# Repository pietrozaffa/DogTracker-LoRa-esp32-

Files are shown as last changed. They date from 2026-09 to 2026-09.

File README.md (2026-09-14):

# PiZaff DogTrack — firmware collare + palmare

Sistema di localizzazione per cani da caccia/ricerca, stile Garmin Astro, tutto
autocostruito su schede **Heltec WiFi LoRa 32 (V3 / V4)**.

- **Collare** — modulo GPS + LoRa che il cane porta al collo. Legge la
  posizione, la trasmette via radio, dorme il più possibile per durare a
  batteria.
- **Palmare** — ricevitore con display OLED, encoder e bussola. Mostra fino a
  **6 cani** contemporaneamente su schermata "freccia + distanza", tiene la
  traccia di ognuno e la può esportare in GPX da una mini pagina web.

Comunicazione **LoRa punto-punto a 869 MHz** (banda EU, rete privata), nessun
server, nessuna SIM, nessuna copertura cellulare richiesta.

---

## Contenuto del repository

| Percorso | Cosa contiene |
|---|---|
| `collare/` | Progetto PlatformIO del collare (`src/main.cpp`, ~1000 righe) |
| `palmare/` | Progetto PlatformIO del palmare (`src/main.cpp`, ~3100 righe) + tabelle partizioni |
| `palmare dogtrk.stl` / `.3mf` | Case del palmare pronto per la stampa 3D |
| `PiZaff_DogTrack_Manuale_A5 (2).pdf` | Manuale utente (formato A5) |
| `PiZaff_DogTrack_Libretto (1).pdf` | Libretto di istruzioni |
| `PiZaff_DogTracker_Schema (3).html` | Schema dei collegamenti (apribile nel browser) |
| `demo_gui.html` / `demo_oled.html` | Anteprima dell'interfaccia palmare, da aprire nel browser |

---

## Hardware

### Collare
- Heltec WiFi LoRa 32 **V3** (ESP32-S3, SX1262, 8 MB flash) **oppure V4**
  (16 MB flash, PA RF esterno ~28 dBm)
- GPS **u-blox NEO-M8N** (UART)
- Accelerometro **MPU6050** (I²C) — rileva se il cane si muove
- **Reed switch** + magnete — accensione/spegnimento senza pulsanti né fori
- Buzzer (feedback sonoro su accensione / reset)
- Batteria LiPo 1S

### Palmare
- Heltec WiFi LoRa 32 **V3** oppure **V4** (la V4 ha 2 MB di PSRAM: buffer
  traccia da 300 → 5000 punti per cane)
- GPS **u-blox NEO-M8N** (UART)
- Bussola **QMC5883L** (I²C) — anche quella integrata nei moduli "M8N + compass"
- Display **OLED 128×64** SSD1309/SSD1306 (SPI), es. Waveshare 2.42"
- **Encoder rotativo KY-040** con pulsante — unico controllo
- Batteria LiPo 1S

I pinout completi (con le differenze V3/V4) sono commentati in testa ai
rispettivi `src/main.cpp`. Lo schema visuale è in
`PiZaff_DogTracker_Schema (3).html`.

> **Nota V4:** su V3 e V4 alcuni GPIO cambiano funzione (sulla V4 sono
> riservati all'amplificatore RF, al connettore GNSS e al reset OLED
> integrati). Il firmware se ne occupa da solo tramite il flag `BOARD_V4`;
> basta scegliere l'ambiente di build giusto.

---

## Compilazione e flash

### Con PlatformIO (consigliato)

Installa l'estensione **PlatformIO** in VS Code, poi apri **la cartella
`collare/` o `palmare/`** (non la root del repo — sono due progetti separati).

Collare:

```bash
cd collare
pio run -e collare_v4 -t upload   # Heltec V4 (16 MB, PA esterno)
pio run -e collare_v3 -t upload   # Heltec V3 (8 MB)
```

Palmare:

```bash
cd palmare
pio run -e palmare_v4 -t upload   # Heltec V4 — usa partitions_pizaff_16mb.csv, PSRAM QSPI
pio run -e palmare_v3 -t upload   # Heltec V3 — usa partitions_pizaff.csv
```

Monitor seriale: `pio device monitor` (115200 baud). In VS Code l'ambiente si
sceglie dalla barra di stato in basso.

Le librerie (RadioLib, TinyGPSPlus, MPU6050 / Adafruit SSD1306+GFX,
QMC5883LCompass) vengono scaricate in automatico da `platformio.ini`.

### Con Arduino IDE

Il file `.csv` delle partizioni **non viene letto**. Per il palmare imposta a
mano:

- **Tools → Partition Scheme →** `Huge APP (3MB No OTA/1MB SPIFFS)`
- solo V4: **Tools → PSRAM →** `QSPI PSRAM`
- **Tools → Filesystem →** LittleFS

Il collare sta nella partizione di default, nessuna impostazione particolare.

---

## Primo utilizzo

### Collare (nessun pulsante, si usa il magnete)

| Gesto | Effetto |
|---|---|
| Magnete appoggiato **2 s** da spento | **Accensione** (5 beep) |
| Magnete appoggiato **3 s** da acceso | **Spegnimento** (deep sleep, sveglia solo a magnete) |
| Magnete tenuto **10 s** all'accensione | **Reset di fabbrica** dei parametri radio (SF/potenza) |

Il tempo minimo evita accensioni/spegnimenti accidentali (collare vicino a
oggetti metallici). All'accensione il collare cerca il fix GPS e comincia a
trasmettere; il LED/buzzer danno conferma.

### Palmare (solo l'encoder: ruota per muoverti, click per confermare)

1. **Accendi** premendo il pulsante dell'encoder.
2. Vai su **Menu → Associa**: il palmare elenca gli ID dei collari che sente in
   giro. Seleziona quello del tuo cane e dagli un nome (max 8 caratteri).
   Ripeti per ogni cane (fino a 6).
3. Torna alla **Home**: per ogni cane vedi freccia (direzione relativa alla tua
   bussola), distanza, stato fix, batteria del collare.
4. **Menu → Bussola**: calibrazione bussola (ruota il palmare su sé stesso).
5. **Menu → Mappa**: attiva il WiFi per la mappa live nel browser (vedi sotto).
6. **Menu → Tracce**: elenco delle tracce registrate, cancellazione, export GPX.
7. **Menu → Unità**: metri / piedi.
8. **Menu → Avanzate**: cambio Spreading Factor e potenza TX (vedi "Come
   funziona").

Spegnimento: voce di menu dedicata / click lungo dalla Home (deep sleep,
sveglia col pulsante encoder).

---

## Come funziona

### Il collegamento radio

- **869.525 MHz**, banda 125 kHz, CR 4/5, sync word privata `0xA7`.
- **SF (Spreading Factor) 8** di default — compromesso tra portata e frequenza
  di aggiornamento. Modificabile da palmare (SF 7–12): SF alto = più portata ma
  refresh più lento e più aria occupata.
- Pacchetto **binario compatto** (`CollarPacket`, ~30 byte) con CRC gestito da
  RadioLib: magic, ID collare, lat/lon (1e-7°), quota, velocità, rotta,
  satelliti, HDOP, batteria %, mV, contatore di sequenza + flag
  (fix / in movimento / batteria scarica / fermo / in carica).
- Il palmare risponde con `CmdPacket` (`ACK`, `STANDBY`, `WAKE`,
  `SET_SF`, `SET_PWR`).

### TX adattivo (autonomia del collare)

L'MPU6050 dice se il cane si muove:

| Stato | Intervallo TX |
|---|---|
| In movimento (o entro 15 s dall'ultimo movimento) | **2.5 s** |
| Fermo | **30 s** |

Cane fermo = poche trasmissioni = batteria che dura. Fra un invio e l'altro,
quando può, il collare va in sleep.

### Standby e sveglia da remoto

Dal palmare (**Cani → Standby**) si mette un collare in standby: la radio resta
in ascolto a bassissimo consumo e il collare si risveglia solo quando il
palmare gli manda `WAKE` (**Cani → Sveglia**). Utile per il cane a riposo tra
una battuta e l'altra senza doverlo maneggiare.

### Auto-recupero SF

Se il palmare perde il contatto, prova a ri-sincronizzarsi mandando `SET_SF` in
broadcast sui vari SF finché il collare non risponde. Il reset di fabbrica col
magnete (10 s) è la via di recupero manuale sul collare, che non ha schermo.

### Potenza TX e limiti EU

Sulla **V4** l'amplificatore esterno porta l'uscita a ~28 dBm. L'ERP dipende
dall'antenna:

| Config | ERP stimato | Limite EU (27 dBm ERP) |
|---|---|---|
| V4 + antenna 10 dBi | ~35.9 dBm | usa **12–13 dBm** di TX |
| V4 + antenna FPC 2.5 dBi | ~28.4 dBm | usa **19–20 dBm** di TX |

`LORA_PWR_DBM` nel `main.cpp` del collare (e la voce **Avanzate → Potenza** sul
palmare) regolano questo valore. **Rispetta la normativa del tuo paese.**

> A piena potenza il PA della V4 assorbe parecchia corrente durante l'impulso
> TX: se vedi riavvii casuali in trasmissione è un calo di tensione (batteria
> scarica o cavi/connettori troppo sottili) — scendi di qualche dBm.

### Mappa e tracce (WiFi del palmare)

Con **Menu → Mappa** il palmare accende un access point:

- SSID **`Pi_zaff_sys_DogTrack`**, password **`pizaff123`**
- apri **http://192.168.4.1** nel browser

La pagina mostra la posizione live dei cani e la scia. Le tracce complete sono
salvate su **LittleFS** e scaricabili in **GPX** da `/tracks`. Il buffer in RAM
serve solo a disegnare la scia sulla mappa live (300 punti/cane su V3, 5000 su
V4 grazie alla PSRAM); lo storico su file non ha questo limite.

---

## Struttura dei sorgenti

Entrambi i `main.cpp` hanno in testa un commento lungo che spiega pinout,
differenze V3/V4, e le scelte non ovvie (gestione PA RF esterno, `gpio_hold_en`
prima del deep sleep, perché serve la tabella partizioni custom sul palmare,
ecc.). È la prima cosa da leggere prima di mettere mano al codice.

---

## Licenza

Copyright (C) 2026 Pietro Zaffarano.

Questo progetto è distribuito con licenza **GNU GPL v3.0**: puoi usarlo,
studiarlo, modificarlo e ridistribuirlo, ma ogni derivato che distribuisci
deve restare open source con la stessa licenza — non può essere chiuso in un
prodotto proprietario né essere fatto passare per opera di qualcun altro.
Testo completo in [LICENSE](LICENSE).

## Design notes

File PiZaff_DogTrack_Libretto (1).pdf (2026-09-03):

# Note — manutenzione

Interventi fatti, parti sostituite, date di ricarica.

# Pi_Zaff System DogTrack

### Sistema di localizzazione GPS per cani da caccia Collare + Palmare · radio LoRa 868 MHz

MANUALE D'USO · firmware v2.14

Sistema autocostruito su hardware Heltec WiFi LoRa 32 (V3/V4).
Fino a 6 collari associabili · mappa da smartphone · tracce esportabili in GPX.

# Indice

### 1 Com'è fatto il sistema

### 2 Cosa c'è nella confezione

### 3 Accendere e spegnere

### 4 La schermata principale

### 5 Il menu

### 6 Associare un collare

### 7 Gestire i cani

### 8 Segnali acustici

### 9 La mappa sul telefono

### 10 Le tracce salvate

### 11 Impostazioni

### 12 Ricarica e manutenzione

### 13 Se qualcosa non va

### 14 Dati tecnici

### 15 Note su potenza e normativa

### 16 Pinout della scheda V4

### 17 Schema del collare

### 18 Schema del palmare

### Prima di iniziare

Questo manuale descrive un sistema autocostruito. Non è un prodotto commerciale certificato: alcune funzioni vanno tarate sul campo, e le prestazioni dipendono dal terreno, dal montaggio e dalle antenne usate.

Leggi il capitolo 15 prima del primo uso in esterna. Riguarda i limiti di potenza radio: la configurazione predefinita è impostata al massimo che l'hardware può erogare, che in Europa supera i limiti consentiti con antenne ad alto guadagno.

Il sistema è composto da due apparati che comunicano solo tra loro, senza internet, senza SIM e senza abbonamenti: il collare sul cane e il palmare in mano.

# Note — tarature

Valori modificati e perche': potenza, SF, soglie.

# Note — prove di portata

Distanze raggiunte, zone difficili, valori di SF provati.

# 1. Com'è fatto il sistema

### Due apparati, un collegamento diretto

Il collare legge la posizione dal proprio GPS e la trasmette via radio. Il palmare la riceve, la confronta con la propria posizione e ti mostra distanza e direzione verso il cane.

La radio è di tipo LoRa in collegamento diretto punto-punto: non serve rete telefonica, non serve copertura, non ci sono costi. Funziona anche dove il telefono non prende.

### Cosa vedi e cosa senti

Sul palmare | Cosa indica
Freccia nella bussola | La direzione in cui camminare per raggiungere il cane
Numero grande | Distanza in linea d'aria
Barrette in alto a sinistra | Qualità del collegamento radio col collare
Riquadri C e P | Stato GPS del Collare e del Palmare
Due batterie | Carica del collare (C) e del palmare (P)

Fino a 6 cani. Ogni collare ha un codice univoco: una volta associato, viene riconosciuto da solo a ogni accensione. Sul palmare ruoti la manopola per passare da un cane all'altro.

### Portata realistica

Ambiente | Distanza indicativa
Campo aperto, in vista | 3–5 km
Collina, vegetazione rada | 1.5–3 km
Bosco fitto | 800 m – 1.5 km

Sono valori indicativi: la portata reale dipende molto dal dislivello, dall'umidità e da come è orientata l'antenna del collare mentre il cane si muove.

Quando il segnale manca, il palmare non si svuota: continua a mostrare l'ultima posizione ricevuta, con l'indicazione di quanto tempo è passato. È lì che devi andare a cercare.

# 2. Cosa c'è nella confezione

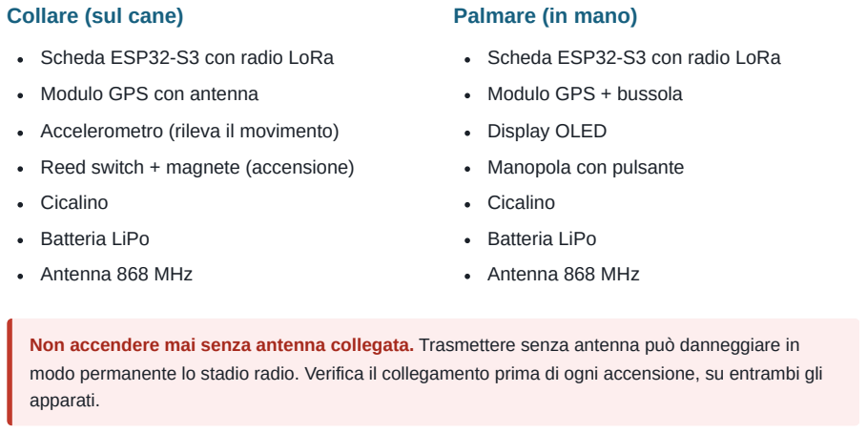
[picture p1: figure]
Collare (sul cane); Scheda ESP32-S3 con radio LoRa; Modulo GPS con antenna; Accelerometro (rileva il movimento); Reed switch + magnete (accensione); Cicalino; Batteria LiPo; Antenna 868 MHz; Palmare (in mano); Modulo GPS + bussola; Display OLED; Manopola con pulsante; apparati.

Non accendere mai senza antenna collegata. Trasmettere senza antenna può danneggiare in modo permanente lo stadio radio. Verifica il collegamento prima di ogni accensione, su entrambi gli

### Il magnete

Il collare non ha pulsanti: è sigillato. Si accende e si spegne appoggiando il magnete sul punto segnato del case. Tienilo insieme al palmare o al portachiavi.

Se il magnete si perde, il collare non si può più accendere né spegnere. Vale la pena averne uno di scorta.

Collare: 2 beep ogni 30 s | Non sente più il palmare

### Rete WiFi

Nome rete | Pi_zaff_sys_DogTrack
Password | pizaff123
Indirizzo | 192.168.4.1

# Riepilogo comandi

Pagina da consultare al volo, senza cercare nel manuale.

### Palmare

Gesto | Effetto
Tieni premuto 2 s | Accende
Tieni premuto 5 s | Spegne (con barra di conferma)
Ruota in schermata principale | Cambia cane
Click in schermata principale | Apre il menu
Ruota nelle liste | Scorre le voci
Ruota nelle schermate informative | Esce
Click dove c'è un'azione extra | Esegue l'azione (spegni WiFi, cancella tracce)

### Collare (magnete)

Durata | Effetto
2 secondi (da spento) | Accende — 1 beep
3 secondi (da acceso o in standby) | Spegne — 3 beep
10 secondi | Ripristino radio — 5 beep rapidi

### Suoni

Suono | Significato
Palmare: 3 toni in discesa | Segnale perso
Palmare: 2 toni in salita | Segnale ritrovato
Palmare: 2 toni lunghi | Cane in ferma
Palmare: 3 beep uguali | Batteria collare quasi scarica
Collare: 3 toni in discesa | Messo in standby dal palmare
Collare: 2 toni in salita | Svegliato dal palmare

# 3. Accendere e spegnere

### Palmare

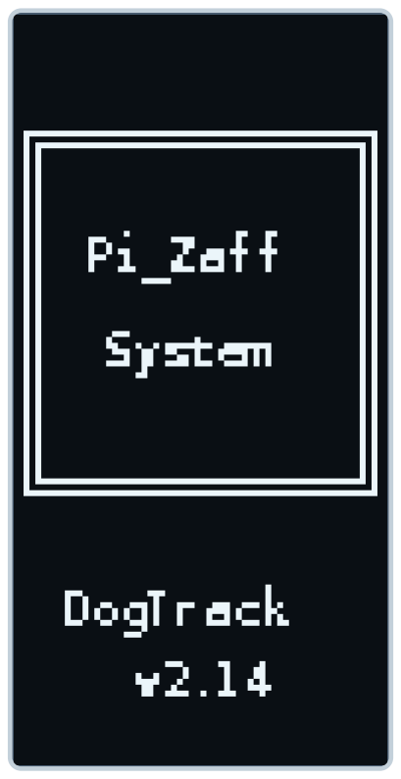
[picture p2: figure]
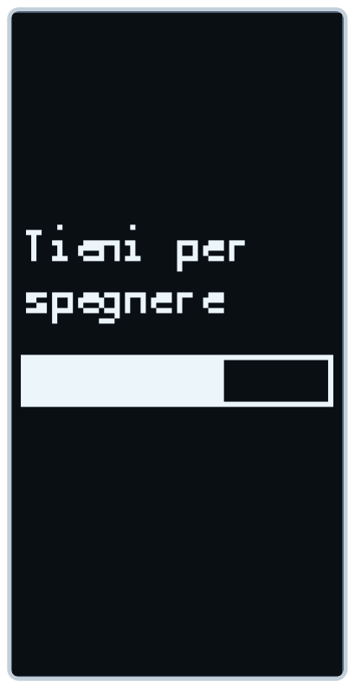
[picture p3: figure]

Schermata di avvio Spegnimento in corso

Accensione
Tieni premuto il pulsante della manopola per 2 secondi. Compare il logo, poi la schermata principale.

Spegnimento
Tieni premuto per 5 secondi. Dopo 1.5 secondi appare una barra che si riempie: quando è piena il palmare si spegne.

I 2 secondi richiesti all'accensione servono a evitare che si accenda da solo urtandolo nello zaino.

### Collare

Operazione | Come si fa | Conferma
Accensione | Magnete appoggiato sul punto segnato per 2 secondi | 1 beep
Spegnimento | Magnete tenuto per 3 secondi, poi toglilo

3 beep

Spegnimento a distanza

Dal palmare puoi mettere un collare in standby senza averlo in mano (Menu → Cani → il cane → Standby). Il collare risponde con tre toni discendenti e si spegne. Per riaccenderlo: stessa strada, voce Sveglia; risponde con due toni ascendenti.

Attenzione alla differenza. Un collare spento col magnete non si può riaccendere da remoto: la radio è completamente spenta. Solo lo standby dal palmare può essere annullato a distanza. Se prevedi di riaccenderlo senza averlo in mano, usa lo standby, non il magnete.

Collare in standby. Il magnete tenuto 3 secondi su un collare in standby lo spegne del tutto (tre beep), non lo risveglia. È lo stesso gesto dello spegnimento normale: non devi ricordarti in che stato fosse.

# 4. La schermata principale

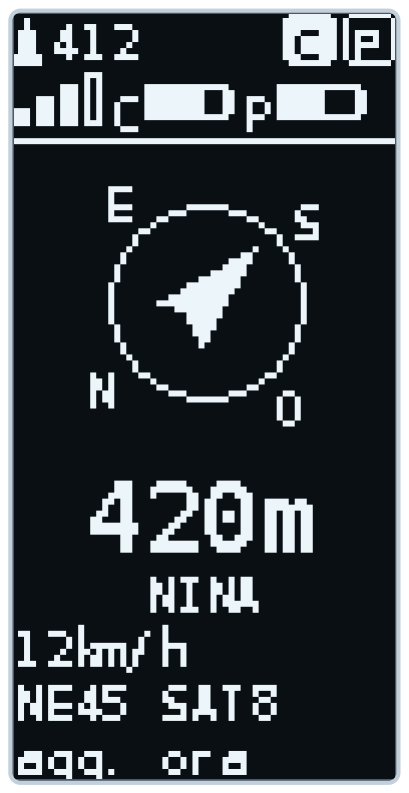
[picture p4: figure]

Situazione normale

Dall'alto verso il basso

Quota (con il triangolino): altitudine dell'ultima posizione del cane. Ogni 5 secondi lascia il posto per 3 secondi all'orologio (con la sua iconcina): l'ora italiana viene calcolata dai satelliti, cambio ora legale compreso, senza bisogno di regolarla.
Riquadri C e P (in alto a destra): stato del GPS di Collare e Palmare. Pieno = posizione valida; vuoto = sta cercando i satelliti; lampeggiante = nessun dato. Se un telefono è collegato al WiFi, al posto della P compare l'icona del telefono.

Cambiando cane con la manopola, per 3 secondi compare il contatore (es. 2/3 ) al posto di quota e orologio.

Barrette + due batterie: qualità del collegamento, carica del collare (C) e del palmare (P).
Bussola: la freccia punta verso il cane; le lettere N/E/S/O ruotano con te. Numero grande: distanza. Subito sotto, centrato, il nome del cane: fino a 6 lettere, ben leggibile.

Ultime tre righe: cosa sta facendo il cane, direzione e satelliti, quando è arrivato l'ultimo aggiornamento.

La freccia è relativa a te. Se punta in alto, il cane è davanti a te così come stai tenendo il palmare. Ruotando il palmare la freccia si aggiorna: giragli attorno finché non punta in alto, poi cammina dritto.

### Le tre situazioni che devi riconoscere

Il magnete e la bussola. Se tieni il magnete del collare nello stesso case del palmare, calibra la bussola con il magnete già al suo posto: il campo fisso viene compensato. Spostandolo dopo, la freccia sbaglia finché non lo rimetti dov'era.

Pi_Zaff System · DogTrack · manuale d'uso firmware v2.14
Sistema autocostruito — nessuna garanzia implicita di funzionamento o conformità

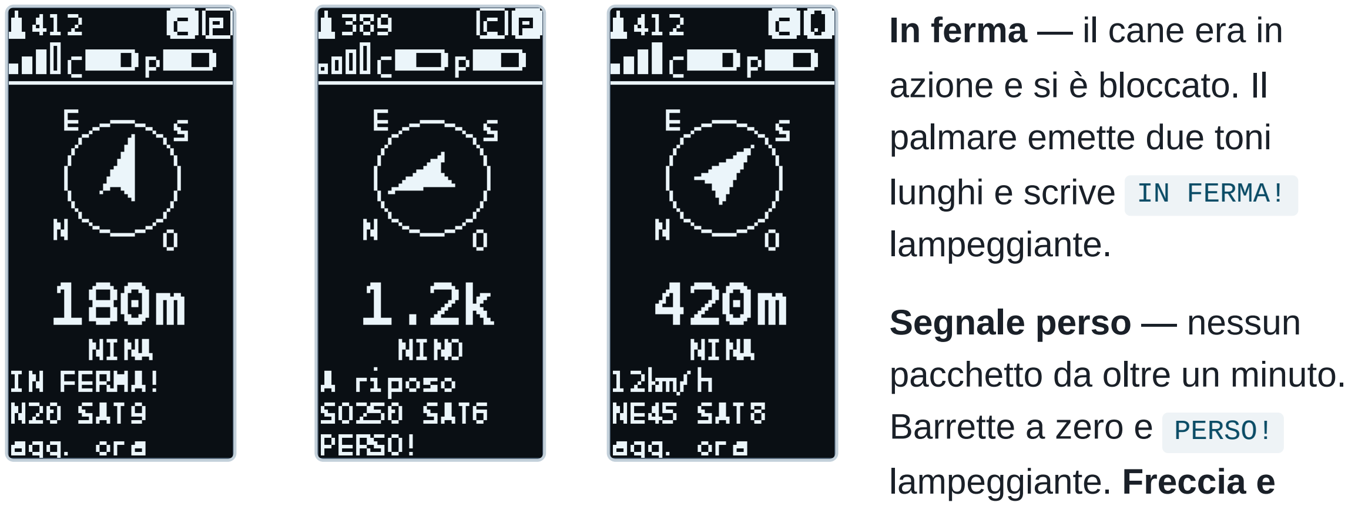
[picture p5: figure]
In ferma — il cane era in azione e si è bloccato. Il palmare emette due toni lunghi e scrive IN FERMA! lampeggiante.; Segnale perso — nessun pacchetto da oltre un minuto. Barrette a zero e PERSO! lampeggiante. Freccia e

# 18. Schema del palmare

Modulo | Suo pin | Pin scheda | Note
GPS + bussola | TX | GPIO 33 | Incrociato
RX | GPIO 16 | Su V3: GPIO 34
SDA | GPIO 41 | Bussola
SCL | GPIO 42 | Bussola
VCC | 3V3
GND | GND
Display | CLK | GPIO 38
DIN | GPIO 39
CS | GPIO 40

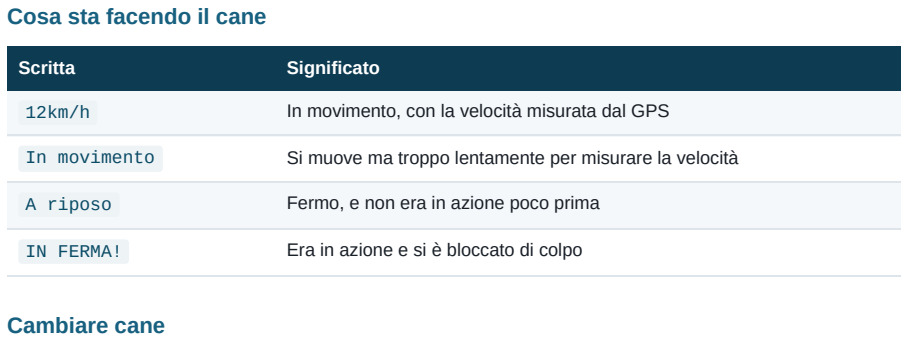
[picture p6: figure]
Cosa sta facendo il cane; Scritta; Significato; Cambiare cane

DC GPIO 15 Su V3: GPIO 21 | A riposo | Fermo, e non era in azione poco prima
RST | GPIO 47
| VCC | 3V3
| GND | GND
Manopola | CLK (A) | GPIO 2 | Vedi avvertenza sotto
| DT (B) | GPIO 6
| SW | GPIO 4 | Su V3: GPIO 7
| + | 3V3
| GND | GND
Cicalino | + | GPIO 21 | Vedi avvertenza
| − | GND
Batteria | JST | connettore scheda
Antenna | u.FL | connettore scheda

### Posizionamento nel case

Display in verticale, con il connettore verso il basso

Bussola lontana dal magnete: almeno 6–7 cm, angolo opposto del case Bussola lontana dalla batteria e da parti metalliche
Manopola raggiungibile con una mano sola: la userai con i guanti

In ferma
lampeggia + doppio tono

Segnale perso
ultima posizione nota

Telefono connesso
icona al posto della P

distanza restano sull'ultima posizione buona.

Telefono connesso —
l'icona del telefono
sostituisce la P quando
qualcuno sta guardando la
mappa dal cellulare.
12km/h | In movimento, con la velocità misurata dal GPS
In movimento | Si muove ma troppo lentamente per misurare la velocità
IN FERMA! | Era in azione e si è bloccato di colpo

In questa schermata ruota la manopola per passare da un cane all'altro. Per tre secondi compare in alto il contatore (es. 2/3 ) così sai a quale sei arrivato.

# 5. Il menu

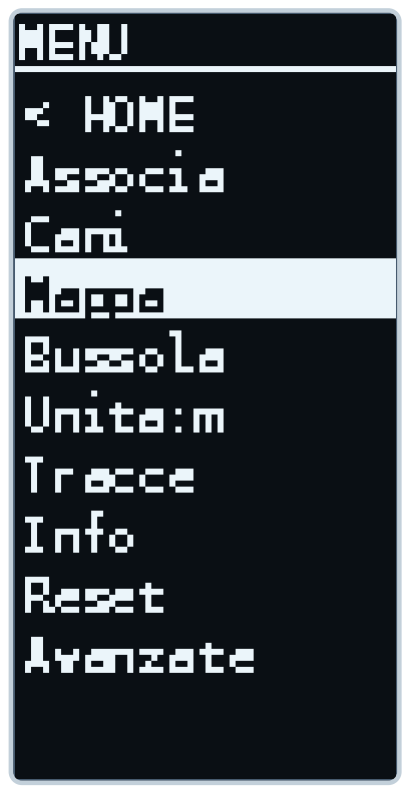
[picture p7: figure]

Le dieci voci del menu

Come ci si muove

RUOTA | Sposta la selezione
CLICK | Conferma / entra
CLICK LUNGO | Solo nell'editor dei nomi: conferma il nome

Una regola sola per uscire: in tutte le schermate informative si esce ruotando la manopola. Nelle liste (Menu, Cani, Avanzate) c'è invece una riga < HOME o < indietro in cima. Dove esiste un'azione in più (Mappa WiFi, Tracce) il click la esegue.

Voce | A cosa serve
< HOME | Torna alla schermata principale
Associa | Registra un collare nuovo (capitolo 6)
Cani | Rinomina, spegni, sveglia o elimina un cane (capitolo 7)
Mappa | Accende il WiFi per vedere la mappa dal telefono (capitolo 9)
Bussola | Avvia la calibrazione della bussola (capitolo 11)
Unita: | Alterna metri/chilometri e piedi/miglia
Tracce | Quante sessioni salvate e quanto spazio occupano (capitolo 10)
Info | Dati tecnici del collegamento e ultima posizione
Reset | Cancella tutto e riporta il palmare come nuovo
Avanzate | Portata del segnale e potenza di trasmissione (capitolo 11)

# 17. Schema del collare

Tutti i collegamenti da fare. Radio, gestione batteria e presa USB sono già cablati sulla scheda: si collegano solo i moduli esterni.

Modulo | Suo pin | Pin scheda | Note
GPS | TX | GPIO 33 | Incrociato: TX del GPS sull'RX della scheda
RX | GPIO 16 | Su V3: GPIO 34
VCC | 3V3 | Mai a 5V
GND | GND
Accelerometro | SDA | GPIO 41
SCL | GPIO 42
VCC | 3V3
GND | GND
Reed switch | capo 1 | GPIO 4 | Su V3: GPIO 7
capo 2 | GND | Non ha polarità
Cicalino | + | GPIO 21 | Tipo passivo. Vedi avvertenza
− | GND
Batteria | JST | connettore scheda | Verificare la polarità
Antenna | u.FL | connettore scheda | Collegare prima di alimentare

### Posizionamento nel case

Antenna GPS rivolta verso l'alto: è la faccia che deve vedere il cielo

Antenna GPS lontana dalla batteria: il pacco può schermare il segnale
Reed switch piatto contro la parete, con la parete assottigliata in quel punto e un segno inciso all'esterno per ritrovarlo
Fili corti e fissati: il collare prende urti e vibrazioni continue
Batteria su biadesivo, mai incollata direttamente

Massa comune. Tutti i GND dei moduli devono arrivare al GND della scheda. Senza massa condivisa i segnali non funzionano o danno letture instabili.

2 5V
alimentazione
— | Da USB
1 | GND massa
—

### Radio, display integrato e altri

| Pin | Stato | Funzione nel progetto
— | GPIO 8 LoRa NSS | RISERV. | Radio — già cablato a bordo
— | GPIO 9
LoRa SCK
RISERV. | Radio
— | GPIO 10
LoRa MOSI
RISERV. | Radio
— | GPIO 11
LoRa MISO
RISERV. | Radio
— | GPIO 12
LoRa RST
RISERV. | Radio
— | GPIO 13
LoRa BUSY
RISERV. | Radio
— | GPIO 14
LoRa DIO1
RISERV. | Radio
— | GPIO 17
OLED SDA
RISERV. | Display integrato
— | GPIO 18
OLED SCL
RISERV. | Display integrato
— | GPIO 15
—
USATO | Display DC (nostro)
— | GPIO 16
—
USATO | GPS RX ← scheda (nostro)

I pin 38–42 sulla V4 sono collegati anche al connettore GNSS dedicato. Restano utilizzabili come pin normali finché quel connettore non viene usato: nel nostro montaggio il GPS è collegato a filo, quindi sono liberi per display e bussola.

Strapping pin. GPIO 3 e 45 vengono letti dal chip all'accensione per decidere come avviarsi. Se un modulo esterno li tiene a livello alto o basso, la scheda può non partire. Vanno lasciati liberi.

Schermata Info

Cosa dice la schermata Info

SF8 | Modalità radio (più alto = più portata, meno velocità)
RSSI | Potenza del segnale ricevuto in dBm (meno negativo = meglio)
SNR | Rapporto segnale/rumore
Cal | Bussola calibrata sì/no
BP / BC | Batteria Palmare / Collare
Pos | Ultima posizione valida del cane
HDOP | Qualità geometrica del fix: sotto 2 ottimo, sopra 10 scarso

# 6. Associare un collare

Va fatto una sola volta per collare. Da lì in poi viene riconosciuto da solo a ogni accensione, anche dopo che la batteria si è scaricata del tutto.

Collari rilevati | Scrittura del nome

Procedura

1. Accendi il collare col magnete e tienilo vicino
2. Sul palmare: Menu → Associa
3. Entro pochi secondi compare il codice del collare
4. Ruota fino a selezionarlo e fai click
5. Scrivi il nome (vedi sotto) e conferma con un click lungo

Se non compare nulla: verifica che il collare sia acceso (1 beep) e che l'antenna sia collegata su entrambi.

Come si scrive il nome

RUOTA | Scorre le lettere disponibili (A–Z, 0–9, spazio)
CLICK | Conferma la lettera e passa alla successiva
CLICK LUNGO | Termina e salva il nome

Il nome può avere fino a 9 caratteri, ma nella schermata principale ne vengono mostrati i primi 6: conviene sceglierlo corto e riconoscibile.

Più cacciatori nella stessa zona? Ogni collare ha un codice unico, quindi non rischi di vedere il cane di un altro. Se però volete isolamento totale tra gruppi, si può cambiare un parametro radio nel firmware — va fatto su tutti gli apparati dello stesso gruppo.

## 16. Pinout V4 (continua)

### Connettore J2 (lato destro)

Pin | Pin | Stato | Funzione nel progetto
18 | GPIO 19 USB_D− · U1RST | RISERV. | USB nativo
17 | GPIO 20
USB_D+ · U1CTS
RISERV. | USB nativo
16 | GPIO 26
SPICS1
RISERV. | Bus flash interno
15 | GPIO 21
OLED_RST
USATO | Cicalino — vedi avvertenza
14 | GPIO 48
—
libero | Non usato
13 | GPIO 47
—
USATO | Display RST
12 | GPIO 33
SPIIO4 · FSPIHD
USATO | GPS TX → scheda
11 | GPIO 34
VGNSS_Ctrl ·
FSPICS0
RISERV. | Alimentazione GNSS
10 | GPIO 35 LED_Write · FSPID | RISERV. | LED integrato
9 | GPIO 36
Vext_Ctrl · FSPICLK
USATO | Alimentazione periferiche
8 | GPIO 0
USER_SW
RISERV. | Pulsante PRG
7 | RST
RST_SW
RISERV. | Pulsante reset
6 | GPIO 43
U0TXD
RISERV. | Console seriale
5 | GPIO 44
U0RXD
RISERV. | Console seriale
4 | Ve
uscita commutata
— | Controllata da GPIO 36
3 | Ve uscita commutata
—

13 GPIO 2
FEM_EN · TOUCH2
USATO | Manopola A — vedi avvertenza
12 | GPIO 1
VBAT_Read ·
ADC1_CH0
USATO | Lettura batteria
11 | GPIO 38
GNSS_RX · FSPIWP
USATO | Display CLK
10 | GPIO 39
GNSS_TX · MTCK
USATO | Display DIN
9 | GPIO 40
GNSS_Wake ·
MTDO
USATO | Display CS
8 | GPIO 41
GNSS_PPS · MTDI
USATO | Bussola SDA
7 | GPIO 42
GNSS_RST · MTMS
USATO | Bussola SCL
6 | GPIO 45
—
STRAP. | Strapping (VDD_SPI)
5 | GPIO 46
FEM_PA
RISERV. | Amplificatore RF
4 | GPIO 37
ADC_Ctrl · FSPIQ
USATO | Abilita partitore batteria
3 | 3V3
alimentazione
— | Moduli esterni
2 | 3V3
alimentazione

—

1 GND
massa
— | Massa comune

# 7. Gestire i cani

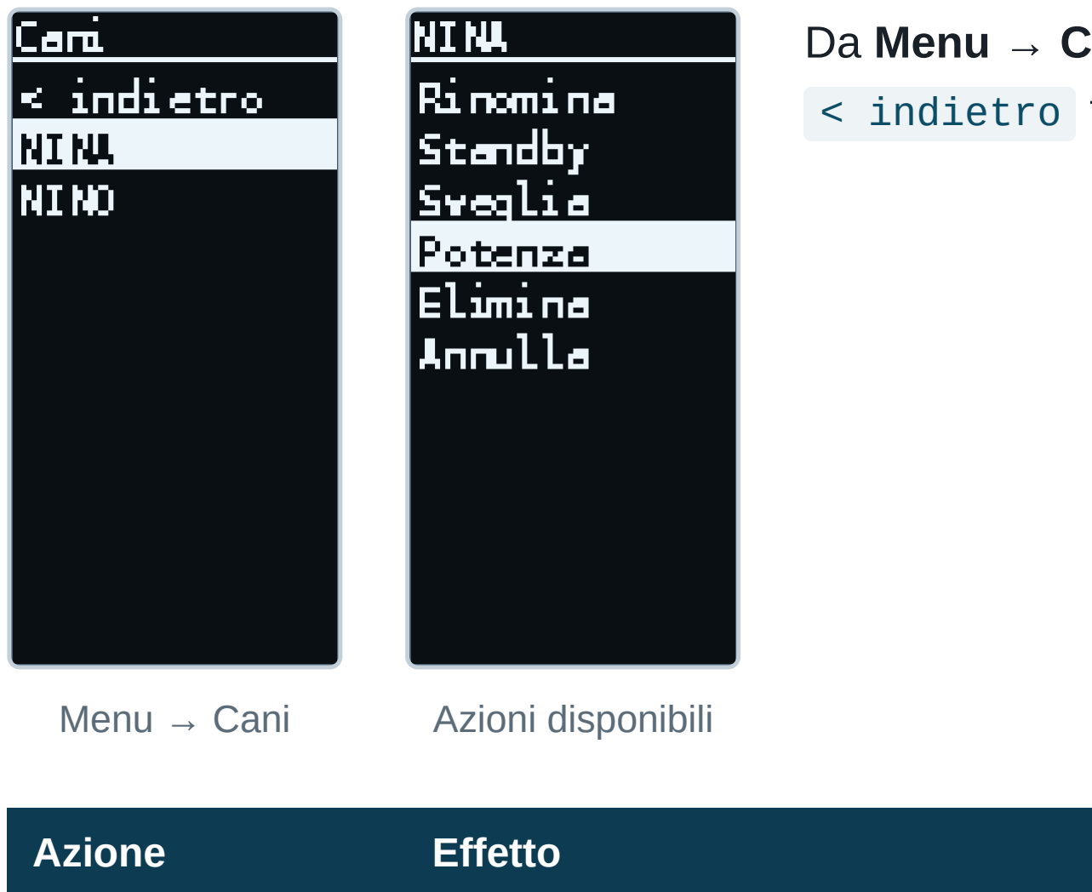
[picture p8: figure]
Menu → Cani; Azioni disponibili; Azione; Effetto

Da Menu → Cani scegli il cane e poi l'azione. La prima riga < indietro torna al menu senza fare nulla.

Rinomina | Cambia il nome, senza perdere l'associazione
Standby | Spegne il collare a distanza. Parte al prossimo pacchetto ricevuto: può servire qualche secondo. Conferma: tre toni discendenti dal collare
Sveglia | Riaccende un collare in standby. Il palmare trasmette per 4 secondi; il collare risponde con due toni ascendenti
Potenza | Cambia la potenza di trasmissione di quel collare (comando via radio). Se il comando si perde, resta il valore precedente
Elimina | Rimuove l'associazione. Chiede conferma
Annulla | Torna indietro

La Sveglia funziona solo dopo uno Standby. Se il collare è stato spento col magnete la sua radio è spenta e non può sentire nulla: va riacceso col magnete.

Eliminare e riassociare

Un collare eliminato non è perso: riaccendendolo ricompare tra quelli rilevabili in Associa e puoi registrarlo di nuovo, anche con un nome diverso.

# 8. Segnali acustici

I suoni sono pochi e volutamente diversi tra loro: servono a farti capire cosa succede senza guardare lo schermo, che in battuta è la cosa che conta.

### Palmare

Suono | Significato
Tre toni discendenti | Segnale col cane perso
Due toni ascendenti | Segnale ritrovato
Due toni lunghi | Il cane è andato in ferma
Tre beep uguali | Batteria del collare quasi scarica

### Collare

Suono | Significato
1 beep | Acceso col magnete
3 beep uguali | Spento col magnete
Tre toni discendenti | Messo in standby dal palmare
Due toni ascendenti | Svegliato dal palmare
2 beep ogni 30 secondi | Non sente più il palmare da oltre un minuto
5 beep rapidi | Magnete tenuto 10 secondi: ripristino radio di emergenza (capitolo 13)

Come distinguerli a orecchio: i toni "in scala" (che salgono o scendono) sono sempre comandi arrivati via radio; i beep tutti uguali sono operazioni fatte col magnete o avvisi di batteria.

Durante la battuta il collare è silenzioso: non suona per non disturbare il cane né la selvaggina. Le uniche eccezioni sono l'accensione, lo spegnimento e l'avviso di collegamento perso.

# 16. Pinout della scheda V4

Riferimento completo dei connettori della scheda Heltec WiFi LoRa 32 V4, con indicazione di cosa è usato dal progetto e cosa non va toccato. Serve se devi rifare un collegamento o aggiungere qualcosa.

USATO usato dal progetto | RISERV. riservato dalla scheda | STRAP. strapping | libero libero

Pin con funzione dedicata sulla V4. Secondo il pin layout ufficiale questi pin sono già impegnati sulla scheda: GPIO 7 e GPIO 2 controllano l'amplificatore radio, GPIO 34 alimenta il connettore GNSS, GPIO 21 resetta il display integrato.

Due eccezioni nel montaggio attuale. Su questo esemplare il GPIO 5 non ha mai risposto (verificato scambiando i fili), quindi la manopola è stata spostata sul GPIO 2; il cicalino è sul GPIO 21 perché i pin provati prima non erano raggiungibili sulla scheda. Entrambi funzionano, ma sono pin che il layout indica come occupati.

Verifica consigliata: con i due apparati distanti qualche decina di metri, guarda l'RSSI in Menu → Info mentre giri la manopola avanti e indietro. Se il valore oscilla o crolla, il GPIO 2 è davvero collegato all'amplificatore e conviene spostare la manopola.

### Connettore J3 (lato sinistro)

Pin | Pin | Stato | Funzione nel progetto
18 | GPIO 7
VFEM_Ctrl ·
TOUCH7 ·
ADC1_CH6
RISERV. | Controllo amplificatore RF
17 | GPIO 6
TOUCH6 ·
ADC1_CH5
USATO | Manopola B
16 | GPIO 5
TOUCH5 ·
ADC1_CH4
libero | Non usato (vedi nota)
15 | GPIO 4
TOUCH4 ·
ADC1_CH3
USATO | Pulsante manopola / reed
14 | GPIO 3
TOUCH3 ·
ADC1_CH2
STRAP. | Strapping (JTAG)

### Perché esistono questi limiti

La banda 868 MHz è condivisa con altri sistemi, alcuni dei quali importanti: antifurti, apparecchiature mediche, sensori industriali. I limiti servono a far convivere tutti. In Italia il superamento dei limiti di emissione è sanzionato dal Codice delle comunicazioni elettroniche.

La responsabilità dell'uso è di chi lo mette in funzione. Questo è un apparato autocostruito, privo di certificazione: sta a te configurarlo in modo conforme alle norme del posto in cui lo usi.

# 9. La mappa sul telefono

Il palmare può creare una rete WiFi propria: collegandoti con il telefono vedi i cani su una mappa vera. Funziona con qualsiasi telefono, Android o iPhone, senza installare niente.

Menu → Mappa

Come collegarsi

1. Sul palmare: Menu → Mappa
2. Sul telefono, tra le reti WiFi scegli Pi_zaff_sys_DogTrack
3. Password: pizaff123
4. Apri il browser: la pagina si apre da sola. Altrimenti digita 192.168.4.1

Ruota per uscire lasciando il WiFi acceso, click per uscire spegnendolo.

### Cosa si vede nella pagina

La tua posizione come freccia che ruota con te
Ogni cane con il suo nome, e la scia del percorso fatto
Schede in basso: distanza, andatura, segnale, satelliti e batteria di ogni cane. Toccando una scheda quel cane diventa quello attivo anche sul palmare
Tasto “i” su ogni scheda: dettagli completi (coordinate, quota, qualità del fix)
Tipo di mappa: stradale, satellite o topografica

Trail: mostra il percorso storico del cane selezionato

Le mappe hanno bisogno di internet. Le immagini della mappa vengono scaricate dal telefono tramite la rete dati mentre resta collegato al palmare. Dove non c'è campo, la pagina passa da sola a una vista radar: cerchi con le distanze e i cani posizionati attorno a te. Funziona completamente

Consuma batteria. Il WiFi acceso incide parecchio sull'autonomia del palmare. Usalo quando ti serve il quadro d'insieme, poi spegnilo (Menu → Mappa → click). Se un telefono è collegato, in alto nella schermata principale l'icona del telefono te lo ricorda.

# 10. Le tracce salvate

Il palmare registra da solo il percorso di tutti i cani, senza che tu debba attivare nulla. Ogni accensione crea una sessione separata.

Menu → Tracce

La schermata mostra quante sessioni sono salvate e quanto spazio occupano.

RUOTA | Esci
CLICK | Vai alla richiesta di cancellazione totale

La cancellazione totale elimina tutte le sessioni e non è recuperabile. Viene chiesta conferma: ruota per annullare.

### Scaricarle sul telefono

1. Collegati alla mappa (capitolo 9)
2. In fondo alla pagina apri Tracce salvate
3. Per ogni sessione: data, cani coinvolti e numero di punti
4. GPX scarica il file, X elimina quella sessione

Il file GPX è un formato standard: si apre in Google Earth, OsmAnd, Garmin BaseCamp e in qualunque programma di cartografia. Contiene una traccia separata per ogni cane, con l'orario di ogni punto — puoi rivedere la battuta come una registrazione.

Lo spazio non si esaurisce mai. Quando la memoria si riempie, la sessione più vecchia viene cancellata automaticamente per fare posto a quella in corso. La battuta di oggi non si perde mai.

Scarica le tracce che ti interessano a fine giornata: una volta sul telefono o sul computer sono al sicuro anche se la pulizia automatica libera spazio in futuro.

# 15. Note su potenza e normativa

Leggi questo capitolo prima del primo uso in esterna. Riguarda un aspetto legale, non solo tecnico.

### Com'è configurato il sistema

Il firmware è impostato al massimo che l'hardware può erogare: 22 dBm dal chip radio, che sulle schede V4 diventano circa 28 dBm in uscita grazie all'amplificatore integrato.

### Il limite europeo

In Europa, sulla banda usata da questo sistema, il limite di potenza irradiata (ERP) è di 27 dBm. La potenza irradiata non dipende solo dalla radio, ma anche dall'antenna:

ERP = potenza in uscita + guadagno antenna − 2.15

Configurazione | ERP risultante | Rispetto al limite
Scheda V4 + antenna 10 dBi | circa 35.9 dBm | ampiamente sopra
Scheda V4 + antenna 2.5 dBi | circa 28.4 dBm | sopra
Scheda V3 + antenna 10 dBi | circa 29.9 dBm | sopra

### Come rientrare nei limiti

Si abbassa un solo valore nel firmware ( LORA_PWR_DBM ) e si ricompila:

Configurazione | Valore da impostare
Scheda V4 con antenna 10 dBi | 12 – 13
Scheda V4 con antenna 2.5 dBi | 19 – 20
Scheda V3 con antenna 10 dBi | 19

Quanto si perde davvero? Meno di quanto sembri. La portata cresce molto lentamente con la potenza: in bosco, dove l'ambiente assorbe gran parte del segnale, la differenza tra il massimo e il valore a norma è dell'ordine del 20–30% di distanza, non del doppio. Per guadagnare portata reale conviene agire sulla modalità radio e sul posizionamento dell'antenna, che rendono di più.

2 – 5 | Buono, adatto all'uso normale
5 – 10 | Discreto: posizione un po' incerta
oltre 10 | Scarso: da non prendere alla lettera

L'HDOP misura come sono disposti i satelliti in cielo, non quanti sono: pochi satelliti ben distribuiti danno una posizione migliore di tanti satelliti ammassati nella stessa zona.

# 11. Impostazioni

### Calibrazione della bussola

Calibrazione in corso

Serve perché il palmare sappia com'è orientato. Senza calibrazione la freccia non è affidabile. Va fatta almeno una volta, e ripetuta se noti che punta in modo strano.

1. Menu → Bussola
2. Muovi il palmare disegnando un otto in aria, ampio, per circa 15 secondi
3. La calibrazione viene salvata: resta anche dopo lo spegnimento

Il magnete disturba la bussola. Fai la calibrazione con il magnete nel suo alloggio abituale, lontano da metalli, auto e strutture in ferro. Se lo togli o lo avvicini, la freccia può sbagliare finché non lo rimetti a posto.

### Unità di misura

Menu → Unita: alterna tra metrico (metri e chilometri) e imperiale (piedi e miglia). La voce mostra l'impostazione attuale.

### Impostazioni dal telefono

Nella pagina della mappa, il pulsante ingranaggio in alto a destra apre le stesse impostazioni con la tastiera del telefono: unità di misura, declinazione magnetica e avvio della calibrazione della bussola.

Declinazione magnetica

È la differenza tra il nord della bussola e il nord delle mappe: cambia da zona a zona. È preimpostata per il sud Italia (+3.5°). Se usi il sistema molto lontano da lì, cerca il valore della tua zona e impostalo.

### Avanzate: portata e potenza

Menu → Avanzate

Qui si regolano i due parametri radio che prima si potevano cambiare solo ricompilando il programma. La riga ? Che sono? apre una spiegazione a schermo.

SF | Quanto lontano arriva il segnale. Valori alti = più portata ma aggiornamenti più lenti
Potenza | Forza di trasmissione del palmare. Non influisce sui collari

Cambiare la potenza

La potenza è indipendente per ogni apparato, quindi cambiarla non ha controindicazioni: quella del palmare si regola da Avanzate, quella di un singolo collare da Cani → il cane → Potenza. Se il comando al collare si perde, resta semplicemente il valore di prima.

Cambiare l'SF: leggere prima di farlo

L'SF deve essere uguale su palmare e collari. Se fossero diversi non si sentirebbero più, e un collare sigillato non si può correggere a mano. Per questo il cambio segue una procedura protetta.

Trasmissione in corso | Riuscito | Annullato

Scelto il nuovo valore, il palmare trasmette il cambio per 40 secondi usando ancora il vecchio SF, così tutti i collari lo ricevono — anche quelli fermi, che trasmettono solo ogni 30 secondi.

Se tutti rispondono, il cambio è confermato. Se anche uno solo non risponde, il palmare torna da solo al valore precedente: meglio rinunciare al cambio che restare senza collegamento.

Non spegnere il palmare durante quei 40 secondi e tieni i collari accesi e a portata. Se qualcosa va storto e un collare resta su un SF diverso, si recupera col magnete: vedi il capitolo 13.

### Reset totale

# 14. Dati tecnici

Voce | Valore
Frequenza radio | 869.525 MHz (banda ISM europea 868)
Tipo di collegamento | LoRa punto-punto diretto, nessuna rete o gateway
Modalità radio | SF regolabile 7–12 (predefinito 8), banda 125 kHz, correzione 4/5
Potenza | Regolabile fino a 22 dBm dal chip, per apparato (vedi capitolo 15)
Aggiornamento posizione | 2.5 s in movimento · 30 s da fermo
Precisione GPS | 2–3 m in campo aperto; 5–10 m sotto vegetazione fitta
Collari associabili | 6
Lunghezza nome | 9 caratteri (6 visibili nella schermata principale)
Memoria tracce | Circolare: la sessione più vecchia lascia posto alla nuova
Esportazione | GPX standard, una traccia per cane
Rete WiFi del palmare | Pi_zaff_sys_DogTrack · password pizaff123 · 192.168.4.1
Watchdog | Attivo: riavvia da solo in caso di blocco del programma
Ricarica | USB-C su entrambi gli apparati

### Cosa significano i numeri del segnale

RSSI | Barrette | Qualità
oltre −95 dBm | 4 | Ottima
−95 / −105 | 3 | Buona
−105 / −113 | 2 | Sufficiente
−113 / −120 | 1 | Al limite
sotto −120 dBm | 0 | Collegamento perso

### HDOP: quanto fidarsi della posizione

Valore | Significato
sotto 2 | Ottimo: satelliti ben distribuiti

### Ripristino radio col magnete

Se un collare resta su parametri radio diversi dal palmare, non lo senti più e non puoi correggerlo da remoto. C'è una via d'uscita che non richiede di aprire il case:

1. Appoggia il magnete sul punto segnato e tienilo per 10 secondi
2. Il collare emette 5 beep rapidi: i parametri radio sono tornati a quelli di fabbrica
3. Riporta anche il palmare allo stesso valore standard (Menu → Avanzate → SF), e torneranno a sentirsi

Il ripristino tocca solo i parametri radio: l'associazione col palmare, il nome del cane e le altre impostazioni restano al loro posto.

Se un apparato resta bloccato su una schermata e non risponde a nulla, l'unico rimedio è scollegare e ricollegare la batteria. Sul collare sigillato questo significa aprire il case.

Menu → Reset cancella tutto: collari associati, nomi, calibrazione e impostazioni. Il palmare riparte come nuovo e i collari vanno riassociati. Le tracce salvate si cancellano invece da Menu → Tracce.

# 12. Ricarica e manutenzione

### Ricarica

Entrambi gli apparati si ricaricano via USB-C, con lo stesso cavo. La ricarica è gestita dalla scheda: si può lasciare collegato senza problemi.

Su un collare sigillato, il connettore USB è il punto più delicato per la tenuta all'acqua. Se il tuo case ha un tappo, richiudilo bene dopo ogni ricarica.

### Autonomia

Situazione | Consumo
Cane in movimento | Massimo: trasmette ogni 2.5 secondi
Cane fermo | Ridotto: trasmette ogni 30 secondi
Batteria sotto il 15% | Gli intervalli raddoppiano automaticamente
Palmare con WiFi acceso | Sensibilmente più alto

L'autonomia va misurata sul campo. Dipende da quanto si muove il cane, dalla temperatura e dalla batteria montata. Prima di fidarti, fai una prova a giornata intera con l'uso reale.

### Pulizia e cura

Sciacqua il collare con acqua dolce dopo fango o pioggia; non usare getti in pressione Controlla ogni tanto che l'antenna sia ben avvitata e il cavo integro
Se non lo usi per settimane, spegni entrambi col magnete e con la pressione lunga
Le batterie al litio si conservano meglio a metà carica: evita di lasciarle scariche per mesi

### Prima di ogni uscita

1. Antenne collegate su entrambi
2. Batterie cariche (visibili nella schermata principale)
3. Collare acceso: 1 beep di conferma
4. Sul palmare, riquadri C e P pieni: entrambi i GPS hanno agganciato
5. Magnete in tasca

# 13. Se qualcosa non va

Sintomo | Causa probabile e rimedio
Il palmare non si accende | Il pulsante va tenuto 2 secondi pieni. Se non basta, la batteria è scarica: collega l'USB e riprova.
Il collare non fa il beep | Magnete non nel punto giusto, o non tenuto 2 secondi. Se il case è spesso il magnete potrebbe essere troppo debole: prova a premerlo bene sul punto segnato.
Il riquadro P lampeggia | Il GPS del palmare non risponde: problema di collegamento interno. Se invece è vuoto ma fisso, sta solo cercando i satelliti — vai all'aperto e attendi.
Il GPS non aggancia mai | Serve cielo libero. Al primo avvio dopo giorni di inattività può richiedere qualche minuto. Sotto tettoie, in auto o in casa spesso non aggancia affatto.
Nessun segnale dal collare | Verifica che sia acceso (1 beep) e associato. Controlla le antenne. Avvicinati: se a pochi metri funziona, è un problema di portata o di ostacoli.

Va peggio da vicino che
lontano

A distanza molto ravvicinata e a piena potenza il ricevitore può saturare. È normale: allontanati di qualche metro.

La freccia punta a caso | Bussola da calibrare (capitolo 11). Verifica anche di non avere il magnete o oggetti metallici vicino al palmare.
Si riavvia mentre trasmette | Non è un difetto del programma ma un calo di tensione: batteria scarica o di scarsa qualità, connettore ossidato, fili di alimentazione sottili.
La pagina mappa non si apre | Controlla di essere collegato alla rete del palmare e non a un'altra. Digita 192.168.4.1 a mano. Il telefono a volte avvisa "rete senza internet": accetta di restare collegato.
Mappa grigia, si vede solo il radar | Manca la copertura dati sul telefono. È il comportamento previsto: il radar funziona comunque e mostra distanze e direzioni.
La Sveglia non funziona | Funziona solo se il collare era in standby. Se era stato spento col magnete, va riacceso col magnete.
Il collare suona due beep ogni 30s | Non sente più il palmare. Verifica che il palmare sia acceso e con antenna collegata.
Un collare non si sente più dopo un cambio SF | È rimasto su un valore diverso. Vedi qui sotto il ripristino radio col magnete.
Compare ERR LoRa | La radio non ha risposto all'avvio: controlla l'antenna e i collegamenti. Il palmare resta comunque spegnibile tenendo premuto 5 secondi, e continua a riprovare da solo.

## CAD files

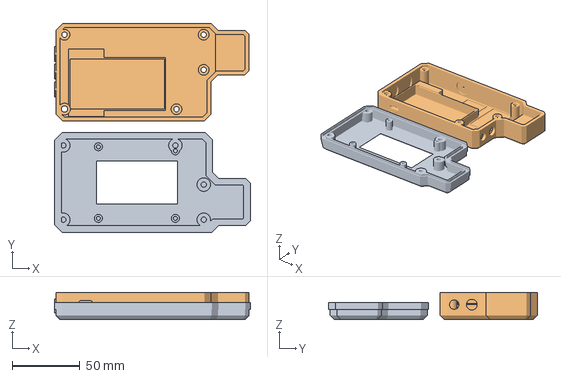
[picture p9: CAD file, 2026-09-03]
palmare dogtrk.3mf
145.1 x 154.5 x 20.0 mm
palmare dogtrk.stl_2
palmare dogtrk.stl_1

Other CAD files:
palmare dogtrk.stl

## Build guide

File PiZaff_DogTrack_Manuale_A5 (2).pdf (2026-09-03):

# Pi_Zaff System DogTrack

### Sistema di localizzazione GPS per cani da caccia Collare + Palmare · radio LoRa 868 MHz

MANUALE D'USO · firmware v2.14

Sistema autocostruito su hardware Heltec WiFi LoRa 32 (V3/V4).
Fino a 6 collari associabili · mappa da smartphone · tracce esportabili in GPX.

# Indice

### 1 Com'è fatto il sistema

### 2 Cosa c'è nella confezione

### 3 Accendere e spegnere

### 4 La schermata principale

### 5 Il menu

### 6 Associare un collare

### 7 Gestire i cani

### 8 Segnali acustici

### 9 La mappa sul telefono

### 10 Le tracce salvate

### 11 Impostazioni

### 12 Ricarica e manutenzione

### 13 Se qualcosa non va

### 14 Dati tecnici

### 15 Note su potenza e normativa

### 16 Pinout della scheda V4

### 17 Schema del collare

### 18 Schema del palmare

### Prima di iniziare

Questo manuale descrive un sistema autocostruito. Non è un prodotto commerciale certificato: alcune funzioni vanno tarate sul campo, e le prestazioni dipendono dal terreno, dal montaggio e dalle

Leggi il capitolo 15 prima del primo uso in esterna. Riguarda i limiti di potenza radio: la configurazione predefinita è impostata al massimo che l'hardware può erogare, che in Europa supera i limiti consentiti con antenne ad alto guadagno.

Il sistema è composto da due apparati che comunicano solo tra loro, senza internet, senza SIM e senza abbonamenti: il collare sul cane e il palmare in mano.

# 1. Com'è fatto il sistema

### Due apparati, un collegamento diretto

Il collare legge la posizione dal proprio GPS e la trasmette via radio. Il palmare la riceve, la confronta con la propria posizione e ti mostra distanza e direzione verso il cane.

La radio è di tipo LoRa in collegamento diretto punto-punto: non serve rete telefonica, non serve copertura, non ci sono costi. Funziona anche dove il telefono non prende.

### Cosa vedi e cosa senti

Sul palmare | Cosa indica
Freccia nella bussola | La direzione in cui camminare per raggiungere il cane
Numero grande | Distanza in linea d'aria
Barrette in alto a sinistra | Qualità del collegamento radio col collare
Riquadri C e P | Stato GPS del Collare e del Palmare
Due batterie | Carica del collare (C) e del palmare (P)

Fino a 6 cani. Ogni collare ha un codice univoco: una volta associato, viene riconosciuto da solo a ogni accensione. Sul palmare ruoti la manopola per passare da un cane all'altro.

### Portata realistica

Ambiente | Distanza indicativa
Campo aperto, in vista | 3–5 km
Collina, vegetazione rada | 1.5–3 km
Bosco fitto | 800 m – 1.5 km

Sono valori indicativi: la portata reale dipende molto dal dislivello, dall'umidità e da come è orientata l'antenna del collare mentre il cane si muove.

Quando il segnale manca, il palmare non si svuota: continua a mostrare l'ultima posizione ricevuta, con l'indicazione di quanto tempo è passato. È lì che devi andare a cercare.

# 2. Cosa c'è nella confezione

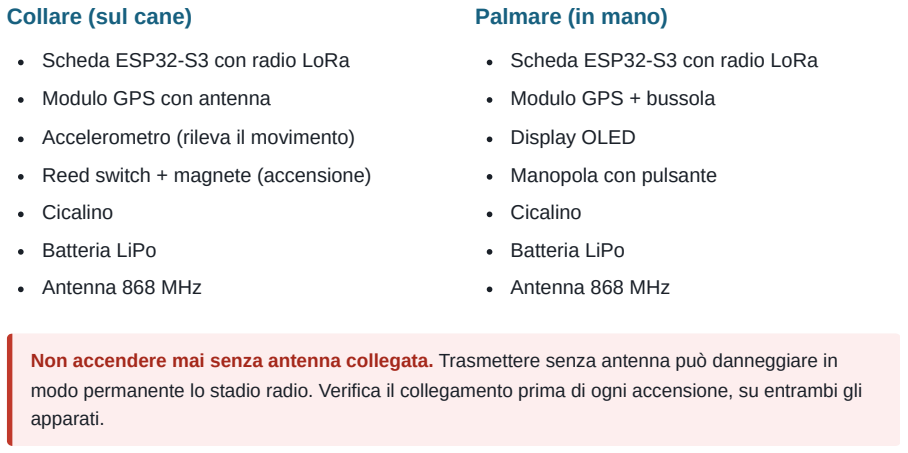
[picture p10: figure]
Collare (sul cane); Scheda ESP32-S3 con radio LoRa; Modulo GPS con antenna; Accelerometro (rileva il movimento); Reed switch + magnete (accensione); Cicalino; Batteria LiPo; Antenna 868 MHz; Palmare (in mano); Modulo GPS + bussola; Display OLED; Manopola con pulsante; apparati.

Non accendere mai senza antenna collegata. Trasmettere senza antenna può danneggiare in modo permanente lo stadio radio. Verifica il collegamento prima di ogni accensione, su entrambi gli

### Il magnete

Il collare non ha pulsanti: è sigillato. Si accende e si spegne appoggiando il magnete sul punto segnato del case. Tienilo insieme al palmare o al portachiavi.

Se il magnete si perde, il collare non si può più accendere né spegnere. Vale la pena averne uno di

# 3. Accendere e spegnere

### Palmare

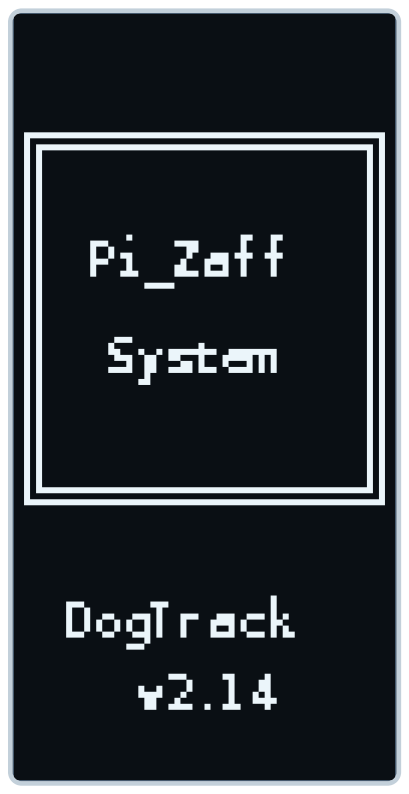
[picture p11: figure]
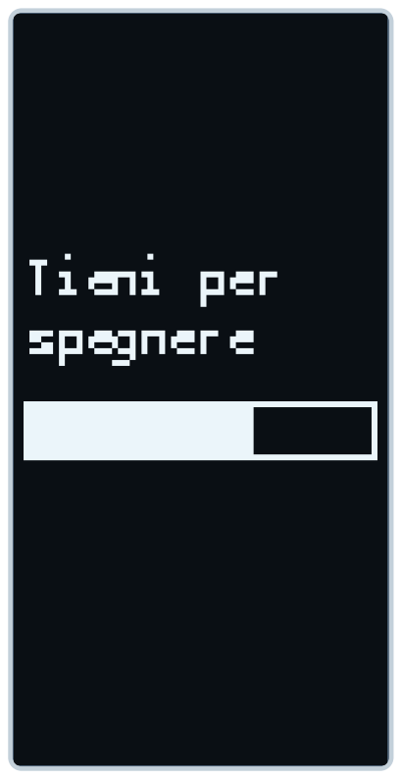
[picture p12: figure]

Schermata di avvio Spegnimento in corso

Accensione
Tieni premuto il pulsante della manopola per 2 secondi. Compare il logo, poi la schermata principale.

Spegnimento
Tieni premuto per 5 secondi. Dopo 1.5 secondi appare una barra che si riempie: quando è piena il palmare si spegne.

I 2 secondi richiesti all'accensione servono a evitare che si accenda da solo urtandolo nello zaino.

### Collare

Operazione | Come si fa | Conferma
Accensione | Magnete appoggiato sul punto segnato per 2 secondi | 1 beep
Spegnimento | Magnete tenuto per 3 secondi, poi toglilo

3 beep

Spegnimento a distanza

Dal palmare puoi mettere un collare in standby senza averlo in mano (Menu → Cani → il cane → Standby). Il collare risponde con tre toni discendenti e si spegne. Per riaccenderlo: stessa strada, voce Sveglia; risponde con due toni ascendenti.

Attenzione alla differenza. Un collare spento col magnete non si può riaccendere da remoto: la radio è completamente spenta. Solo lo standby dal palmare può essere annullato a distanza. Se prevedi di riaccenderlo senza averlo in mano, usa lo standby, non il magnete.

Collare in standby. Il magnete tenuto 3 secondi su un collare in standby lo spegne del tutto (tre beep), non lo risveglia. È lo stesso gesto dello spegnimento normale: non devi ricordarti in che stato

# 4. La schermata principale

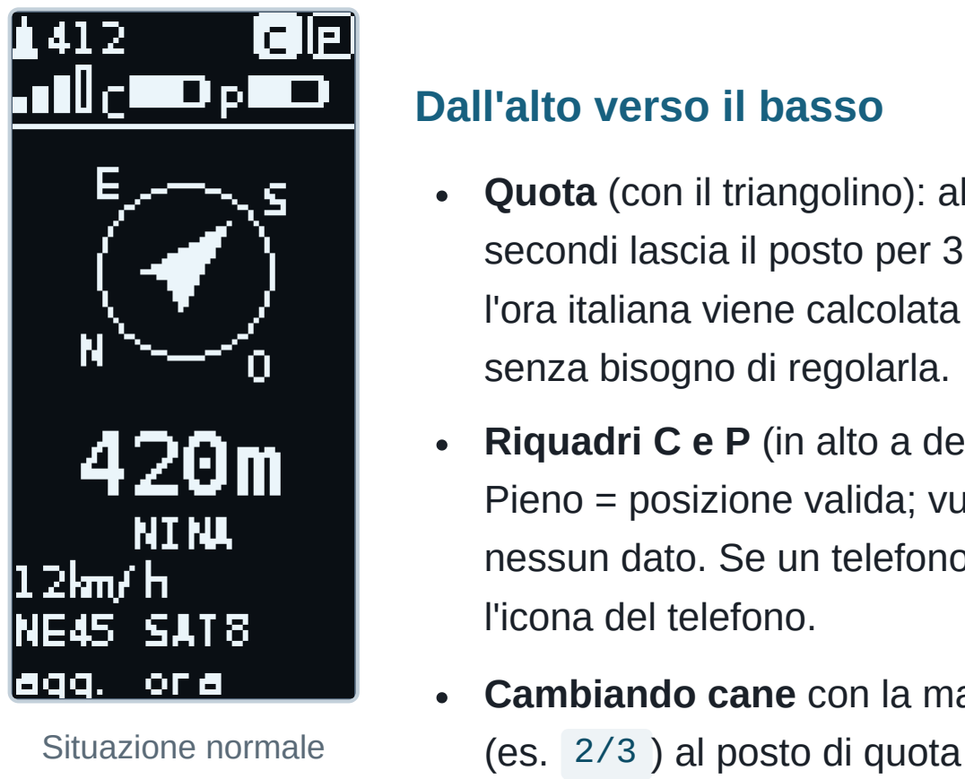
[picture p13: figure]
Situazione normale; Dall'alto verso il basso; senza bisogno di regolarla.; l'icona del telefono.

Quota (con il triangolino): altitudine dell'ultima posizione del cane. Ogni 5 secondi lascia il posto per 3 secondi all'orologio (con la sua iconcina): l'ora italiana viene calcolata dai satelliti, cambio ora legale compreso,

Riquadri C e P (in alto a destra): stato del GPS di Collare e Palmare. Pieno = posizione valida; vuoto = sta cercando i satelliti; lampeggiante = nessun dato. Se un telefono è collegato al WiFi, al posto della P compare

Cambiando cane con la manopola, per 3 secondi compare il contatore (es. 2/3 ) al posto di quota e orologio.

Barrette + due batterie: qualità del collegamento, carica del collare (C) e del palmare (P).
Bussola: la freccia punta verso il cane; le lettere N/E/S/O ruotano con te. Numero grande: distanza. Subito sotto, centrato, il nome del cane: fino a 6 lettere, ben leggibile.

Ultime tre righe: cosa sta facendo il cane, direzione e satelliti, quando è arrivato l'ultimo aggiornamento.

La freccia è relativa a te. Se punta in alto, il cane è davanti a te così come stai tenendo il palmare. Ruotando il palmare la freccia si aggiorna: giragli attorno finché non punta in alto, poi cammina dritto.

### Le tre situazioni che devi riconoscere

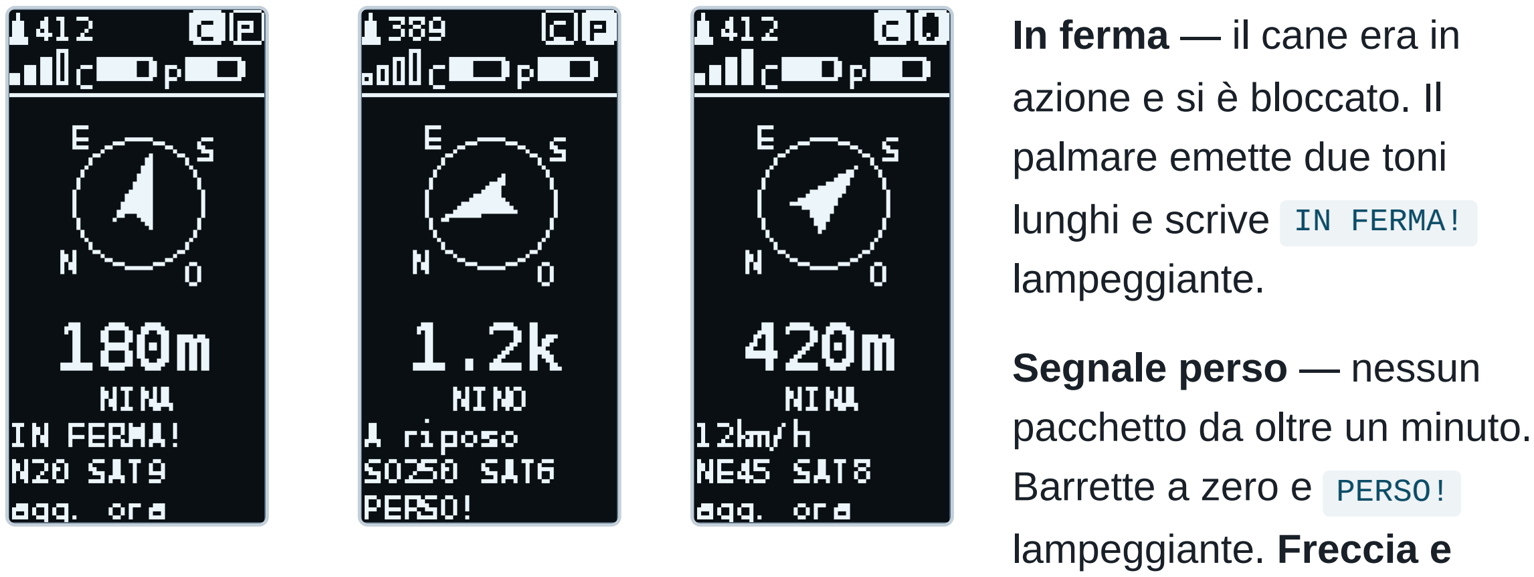
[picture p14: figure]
In ferma — il cane era in azione e si è bloccato. Il palmare emette due toni lunghi e scrive IN FERMA! lampeggiante.; Segnale perso — nessun pacchetto da oltre un minuto. Barrette a zero e PERSO! lampeggiante. Freccia e

In ferma
lampeggia + doppio tono

Segnale perso
ultima posizione nota

Telefono connesso
icona al posto della P

distanza restano sull'ultima posizione buona.

Telefono connesso —
l'icona del telefono
sostituisce la P quando
qualcuno sta guardando la
mappa dal cellulare.

Cosa sta facendo il cane

Scritta | Significato
12km/h | In movimento, con la velocità misurata dal GPS
In movimento | Si muove ma troppo lentamente per misurare la velocità
A riposo | Fermo, e non era in azione poco prima
IN FERMA! | Era in azione e si è bloccato di colpo

Cambiare cane

In questa schermata ruota la manopola per passare da un cane all'altro. Per tre secondi compare in alto il contatore (es. 2/3 ) così sai a quale sei arrivato.

# 5. Il menu

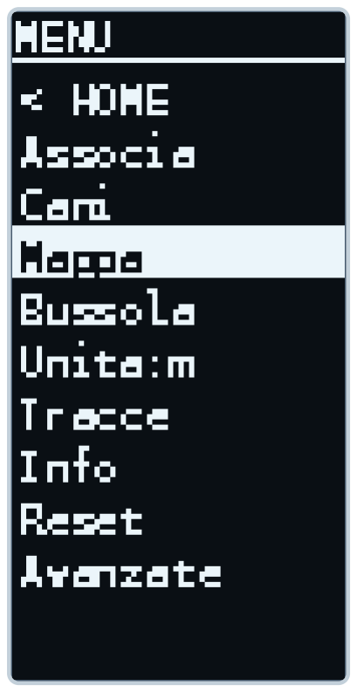
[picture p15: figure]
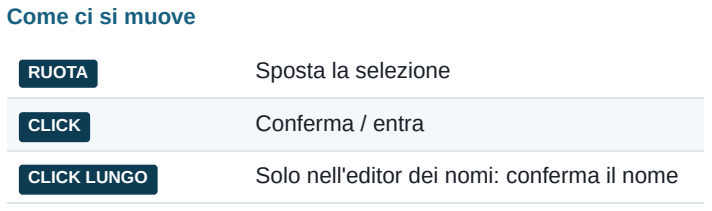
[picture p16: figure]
Come ci si muove; RUOTA; Sposta la selezione; CLICK; Conferma / entra

CLICK LUNGO | Solo nell'editor dei nomi: conferma il nome

Una regola sola per uscire: in tutte le schermate informative si esce ruotando la manopola. Nelle liste (Menu, Cani, Avanzate) c'è invece una riga < HOME o < indietro in cima. Dove esiste un'azione in più (Mappa WiFi,

Voce | A cosa serve
< HOME | Torna alla schermata principale
Associa | Registra un collare nuovo (capitolo 6)
Cani | Rinomina, spegni, sveglia o elimina un cane (capitolo 7)
Mappa | Accende il WiFi per vedere la mappa dal telefono (capitolo 9)
Bussola | Avvia la calibrazione della bussola (capitolo 11)
Unita: | Alterna metri/chilometri e piedi/miglia
Tracce | Quante sessioni salvate e quanto spazio occupano (capitolo 10)
Info | Dati tecnici del collegamento e ultima posizione
Reset | Cancella tutto e riporta il palmare come nuovo
Avanzate | Portata del segnale e potenza di trasmissione (capitolo 11)

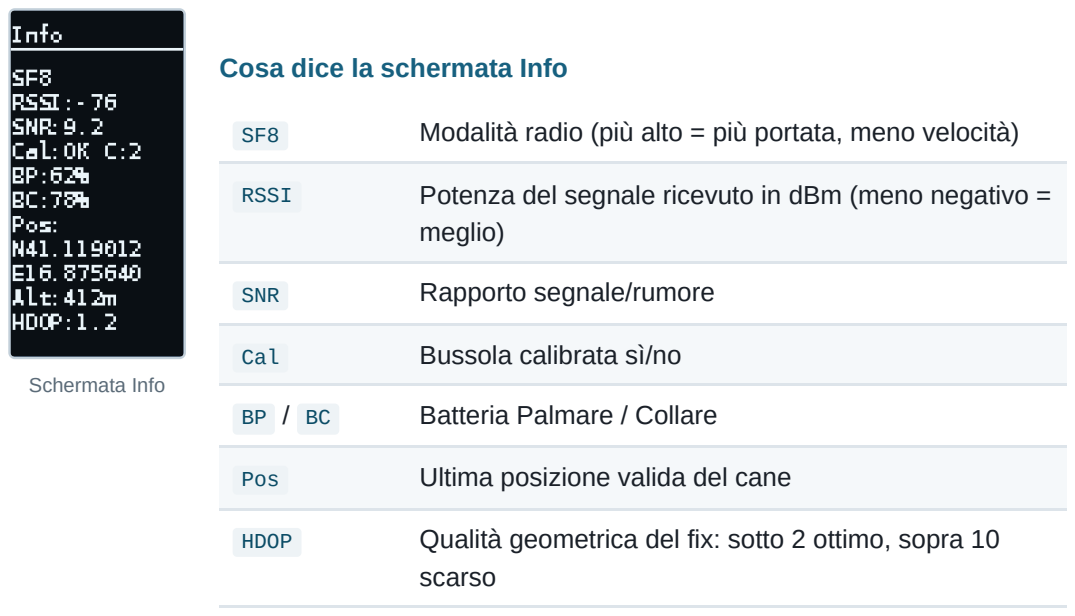
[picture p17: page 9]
Schermata Info; Modalità radio (più alto = più portata, meno velocità); RSSI; Potenza del segnale ricevuto in dBm (meno negativo =; meglio); SNR; Rapporto segnale/rumore; Cal; Bussola calibrata sì/no; Batteria Palmare / Collare; Pos; Ultima posizione valida del cane; HDOP; Qualità geometrica del fix: sotto 2 ottimo, sopra 10; scarso

Cosa dice la schermata Info

# 6. Associare un collare

Va fatto una sola volta per collare. Da lì in poi viene riconosciuto da solo a ogni accensione, anche dopo che la batteria si è scaricata del tutto.

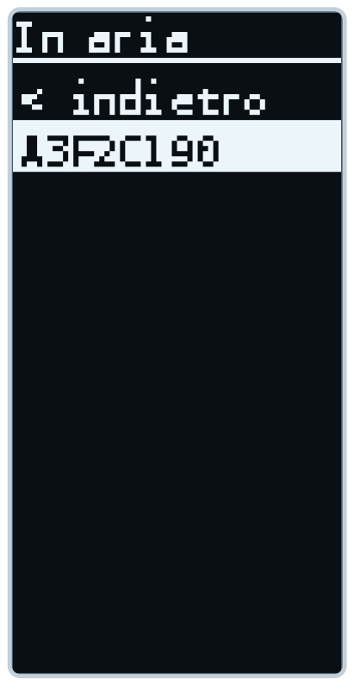
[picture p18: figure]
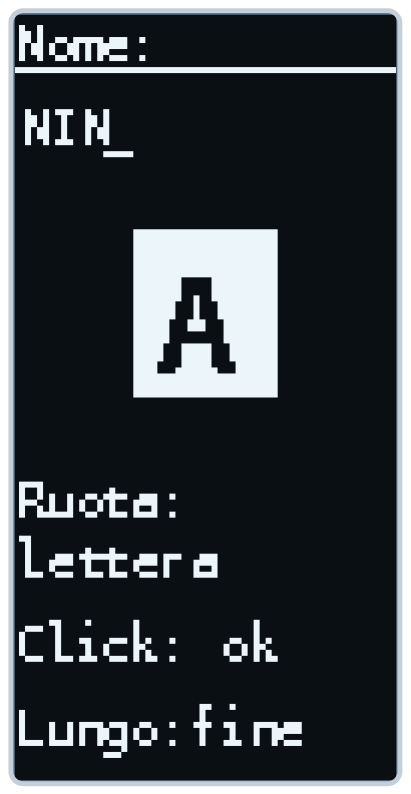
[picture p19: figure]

Collari rilevati | Scrittura del nome

Procedura

1. Accendi il collare col magnete e tienilo vicino
2. Sul palmare: Menu → Associa
3. Entro pochi secondi compare il codice del collare
4. Ruota fino a selezionarlo e fai click
5. Scrivi il nome (vedi sotto) e conferma con un click lungo

Se non compare nulla: verifica che il collare sia acceso (1 beep) e che l'antenna sia collegata su entrambi.

RUOTA | Scorre le lettere disponibili (A–Z, 0–9, spazio)
CLICK | Conferma la lettera e passa alla successiva

Il nome può avere fino a 9 caratteri, ma nella schermata principale ne vengono mostrati i primi 6:

Più cacciatori nella stessa zona? Ogni collare ha un codice unico, quindi non rischi di vedere il cane di un altro. Se però volete isolamento totale tra gruppi, si può cambiare un parametro radio nel firmware — va fatto su tutti gli apparati dello stesso gruppo.

# 7. Gestire i cani

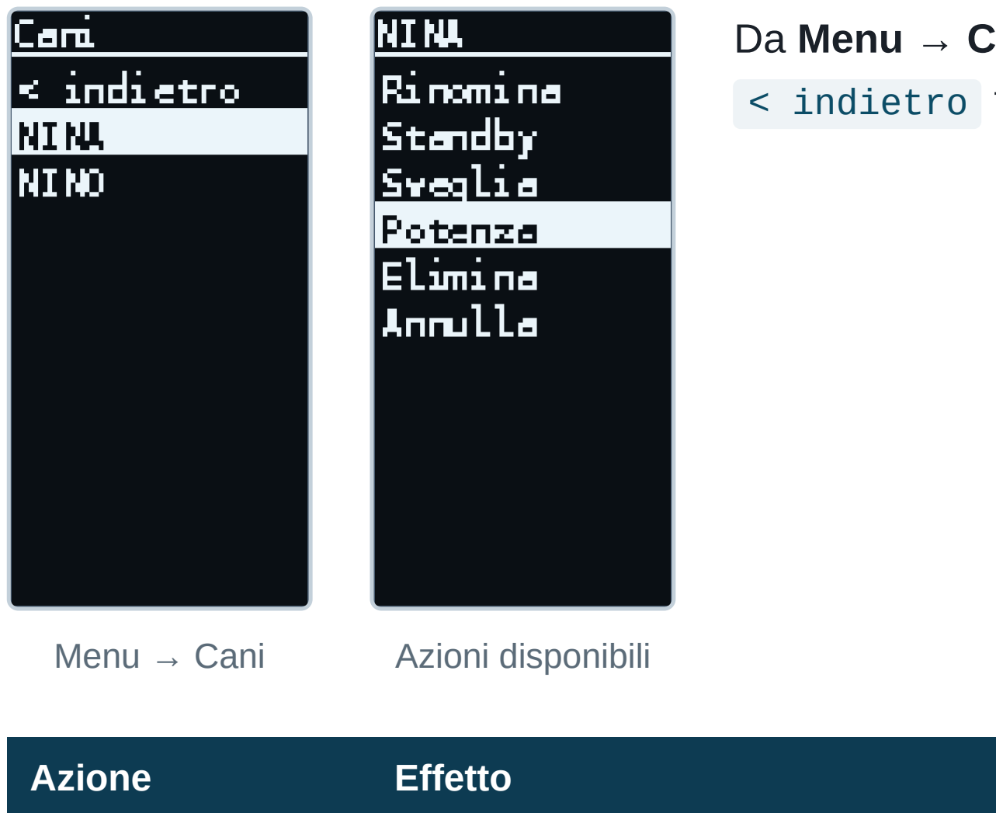
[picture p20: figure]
Menu → Cani; Azioni disponibili; Azione; Effetto

Da Menu → Cani scegli il cane e poi l'azione. La prima riga < indietro torna al menu senza fare nulla.

Rinomina | Cambia il nome, senza perdere l'associazione
Standby | Spegne il collare a distanza. Parte al prossimo pacchetto ricevuto: può servire qualche secondo. Conferma: tre toni discendenti dal collare
Sveglia | Riaccende un collare in standby. Il palmare trasmette per 4 secondi; il collare risponde con due toni ascendenti
Potenza | Cambia la potenza di trasmissione di quel collare (comando via radio). Se il comando si perde, resta il valore precedente

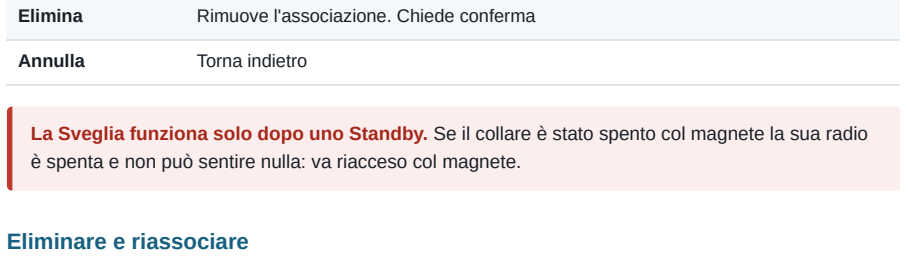
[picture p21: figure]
Elimina; Rimuove l'associazione. Chiede conferma; Annulla; Torna indietro; Eliminare e riassociare

La Sveglia funziona solo dopo uno Standby. Se il collare è stato spento col magnete la sua radio è spenta e non può sentire nulla: va riacceso col magnete.

Un collare eliminato non è perso: riaccendendolo ricompare tra quelli rilevabili in Associa e puoi registrarlo di nuovo, anche con un nome diverso.

# 8. Segnali acustici

I suoni sono pochi e volutamente diversi tra loro: servono a farti capire cosa succede senza guardare lo schermo, che in battuta è la cosa che conta.

### Palmare

Suono | Significato
Tre toni discendenti | Segnale col cane perso
Due toni ascendenti | Segnale ritrovato
Due toni lunghi | Il cane è andato in ferma
Tre beep uguali | Batteria del collare quasi scarica

### Collare

Suono | Significato
1 beep | Acceso col magnete
3 beep uguali | Spento col magnete
Tre toni discendenti | Messo in standby dal palmare
Due toni ascendenti | Svegliato dal palmare
2 beep ogni 30 secondi | Non sente più il palmare da oltre un minuto
5 beep rapidi | Magnete tenuto 10 secondi: ripristino radio di emergenza (capitolo 13)

Come distinguerli a orecchio: i toni "in scala" (che salgono o scendono) sono sempre comandi arrivati via radio; i beep tutti uguali sono operazioni fatte col magnete o avvisi di batteria.

Durante la battuta il collare è silenzioso: non suona per non disturbare il cane né la selvaggina. Le uniche eccezioni sono l'accensione, lo spegnimento e l'avviso di collegamento perso.

# 9. La mappa sul telefono

Il palmare può creare una rete WiFi propria: collegandoti con il telefono vedi i cani su una mappa vera. Funziona con qualsiasi telefono, Android o iPhone, senza installare niente.

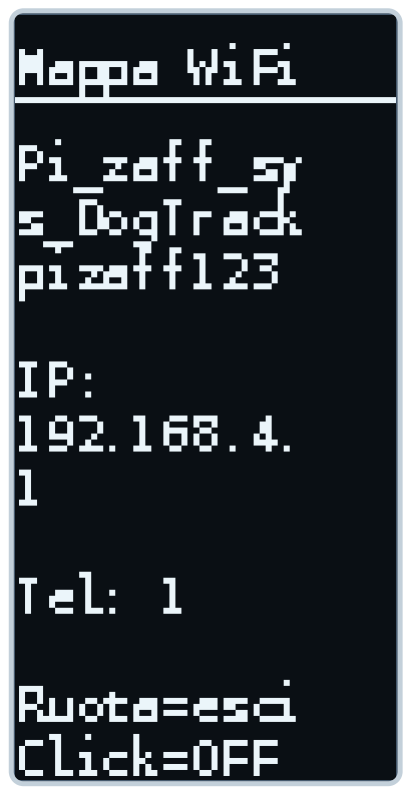
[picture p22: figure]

Menu → Mappa

Come collegarsi

1. Sul palmare: Menu → Mappa
2. Sul telefono, tra le reti WiFi scegli Pi_zaff_sys_DogTrack
3. Password: pizaff123
4. Apri il browser: la pagina si apre da sola. Altrimenti digita 192.168.4.1

Ruota per uscire lasciando il WiFi acceso, click per uscire spegnendolo.

### Cosa si vede nella pagina

La tua posizione come freccia che ruota con te
Ogni cane con il suo nome, e la scia del percorso fatto
Schede in basso: distanza, andatura, segnale, satelliti e batteria di ogni cane. Toccando una scheda quel cane diventa quello attivo anche sul palmare
Tasto “i” su ogni scheda: dettagli completi (coordinate, quota, qualità del fix)
Tipo di mappa: stradale, satellite o topografica

Trail: mostra il percorso storico del cane selezionato

Le mappe hanno bisogno di internet. Le immagini della mappa vengono scaricate dal telefono tramite la rete dati mentre resta collegato al palmare. Dove non c'è campo, la pagina passa da sola a una vista radar: cerchi con le distanze e i cani posizionati attorno a te. Funziona completamente

Consuma batteria. Il WiFi acceso incide parecchio sull'autonomia del palmare. Usalo quando ti serve il quadro d'insieme, poi spegnilo (Menu → Mappa → click). Se un telefono è collegato, in alto nella schermata principale l'icona del telefono te lo ricorda.

# 10. Le tracce salvate

Il palmare registra da solo il percorso di tutti i cani, senza che tu debba attivare nulla. Ogni accensione crea una sessione separata.

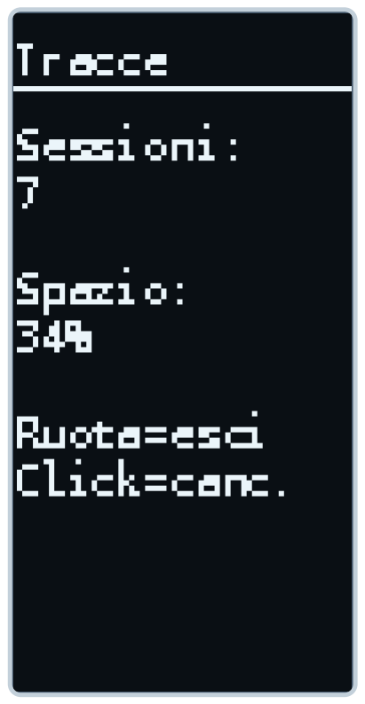
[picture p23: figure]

Menu → Tracce

La schermata mostra quante sessioni sono salvate e quanto spazio occupano.

CLICK | Vai alla richiesta di cancellazione totale

La cancellazione totale elimina tutte le sessioni e non è recuperabile. Viene chiesta conferma: ruota per annullare.

### Scaricarle sul telefono

1. Collegati alla mappa (capitolo 9)
2. In fondo alla pagina apri Tracce salvate
3. Per ogni sessione: data, cani coinvolti e numero di punti
4. GPX scarica il file, X elimina quella sessione

Il file GPX è un formato standard: si apre in Google Earth, OsmAnd, Garmin BaseCamp e in qualunque programma di cartografia. Contiene una traccia separata per ogni cane, con l'orario di ogni punto — puoi rivedere la battuta come una registrazione.

Lo spazio non si esaurisce mai. Quando la memoria si riempie, la sessione più vecchia viene cancellata automaticamente per fare posto a quella in corso. La battuta di oggi non si perde mai.

Scarica le tracce che ti interessano a fine giornata: una volta sul telefono o sul computer sono al sicuro anche se la pulizia automatica libera spazio in futuro.

# 11. Impostazioni

### Calibrazione della bussola

Serve perché il palmare sappia com'è orientato. Senza calibrazione la freccia non è affidabile. Va fatta almeno una volta, e ripetuta se noti che punta in modo strano.

1. Menu → Bussola
2. Muovi il palmare disegnando un otto in aria, ampio, per circa 15 secondi
3. La calibrazione viene salvata: resta anche dopo lo spegnimento

Il magnete disturba la bussola. Fai la calibrazione con il magnete nel suo alloggio abituale, lontano da metalli, auto e strutture in ferro. Se lo togli o lo avvicini, la freccia può sbagliare finché non

### Unità di misura

Menu → Unita: alterna tra metrico (metri e chilometri) e imperiale (piedi e miglia). La voce mostra l'impostazione attuale.

### Impostazioni dal telefono

Nella pagina della mappa, il pulsante ingranaggio in alto a destra apre le stesse impostazioni con la tastiera del telefono: unità di misura, declinazione magnetica e avvio della calibrazione della bussola.

Declinazione magnetica

È la differenza tra il nord della bussola e il nord delle mappe: cambia da zona a zona. È preimpostata per il sud Italia (+3.5°). Se usi il sistema molto lontano da lì, cerca il valore della tua zona e impostalo.

### Avanzate: portata e potenza

Menu → Avanzate

Qui si regolano i due parametri radio che prima si potevano cambiare solo ricompilando il programma. La riga ? Che sono? apre una spiegazione a schermo.

SF | Quanto lontano arriva il segnale. Valori alti = più portata ma aggiornamenti più lenti
Potenza | Forza di trasmissione del palmare. Non influisce sui collari

Cambiare la potenza

La potenza è indipendente per ogni apparato, quindi cambiarla non ha controindicazioni: quella del palmare si regola da Avanzate, quella di un singolo collare da Cani → il cane → Potenza. Se il comando al collare si perde, resta semplicemente il valore di prima.

Cambiare l'SF: leggere prima di farlo

L'SF deve essere uguale su palmare e collari. Se fossero diversi non si sentirebbero più, e un collare sigillato non si può correggere a mano. Per questo il cambio segue una procedura protetta.

Trasmissione in corso | Riuscito | Annullato

Scelto il nuovo valore, il palmare trasmette il cambio per 40 secondi usando ancora il vecchio SF, così tutti i collari lo ricevono — anche quelli fermi, che trasmettono solo ogni 30 secondi.

Se tutti rispondono, il cambio è confermato. Se anche uno solo non risponde, il palmare torna da solo al valore precedente: meglio rinunciare al cambio che restare senza collegamento.

Non spegnere il palmare durante quei 40 secondi e tieni i collari accesi e a portata. Se qualcosa va storto e un collare resta su un SF diverso, si recupera col magnete: vedi il capitolo 13.

### Reset totale

Menu → Reset cancella tutto: collari associati, nomi, calibrazione e impostazioni. Il palmare riparte come nuovo e i collari vanno riassociati. Le tracce salvate si cancellano invece da Menu → Tracce.

# 12. Ricarica e manutenzione

### Ricarica

Entrambi gli apparati si ricaricano via USB-C, con lo stesso cavo. La ricarica è gestita dalla scheda: si può lasciare collegato senza problemi.

Su un collare sigillato, il connettore USB è il punto più delicato per la tenuta all'acqua. Se il tuo case ha un tappo, richiudilo bene dopo ogni ricarica.

### Autonomia

Situazione | Consumo
Cane in movimento | Massimo: trasmette ogni 2.5 secondi
Cane fermo | Ridotto: trasmette ogni 30 secondi

L'autonomia va misurata sul campo. Dipende da quanto si muove il cane, dalla temperatura e dalla batteria montata. Prima di fidarti, fai una prova a giornata intera con l'uso reale.

### Pulizia e cura

Sciacqua il collare con acqua dolce dopo fango o pioggia; non usare getti in pressione Controlla ogni tanto che l'antenna sia ben avvitata e il cavo integro
Se non lo usi per settimane, spegni entrambi col magnete e con la pressione lunga
Le batterie al litio si conservano meglio a metà carica: evita di lasciarle scariche per mesi

### Prima di ogni uscita

1. Antenne collegate su entrambi
2. Batterie cariche (visibili nella schermata principale)
3. Collare acceso: 1 beep di conferma
4. Sul palmare, riquadri C e P pieni: entrambi i GPS hanno agganciato
5. Magnete in tasca

# 13. Se qualcosa non va

Sintomo | Causa probabile e rimedio
Il palmare non si accende | Il pulsante va tenuto 2 secondi pieni. Se non basta, la batteria è scarica: collega l'USB e riprova.
Il collare non fa il beep | Magnete non nel punto giusto, o non tenuto 2 secondi. Se il case è spesso il magnete potrebbe essere troppo debole: prova a premerlo bene sul punto segnato.
Il riquadro P lampeggia | Il GPS del palmare non risponde: problema di collegamento interno. Se invece è vuoto ma fisso, sta solo cercando i satelliti — vai all'aperto e attendi.
Il GPS non aggancia mai | Serve cielo libero. Al primo avvio dopo giorni di inattività può richiedere qualche minuto. Sotto tettoie, in auto o in casa spesso non aggancia affatto.
Nessun segnale dal collare | Verifica che sia acceso (1 beep) e associato. Controlla le antenne. Avvicinati: se a pochi metri funziona, è un problema di portata o di ostacoli.
Va peggio da vicino che lontano | A distanza molto ravvicinata e a piena potenza il ricevitore può saturare. È normale: allontanati di qualche metro.
La freccia punta a caso | Bussola da calibrare (capitolo 11). Verifica anche di non avere il magnete o oggetti metallici vicino al palmare.
Si riavvia mentre trasmette | Non è un difetto del programma ma un calo di tensione: batteria scarica o di scarsa qualità, connettore ossidato, fili di alimentazione sottili.
| Controlla di essere collegato alla rete del palmare e non a un'altra. Digita 192.168.4.1 a mano. Il telefono a volte avvisa "rete senza internet":

Manca la copertura dati sul telefono. È il comportamento previsto: il radar funziona comunque e mostra distanze e direzioni.

La Sveglia non funziona | Funziona solo se il collare era in standby. Se era stato spento col magnete, va riacceso col magnete.
Il collare suona due beep ogni 30s | Non sente più il palmare. Verifica che il palmare sia acceso e con antenna collegata.
Un collare non si sente più dopo un cambio SF | È rimasto su un valore diverso. Vedi qui sotto il ripristino radio col magnete.
Compare ERR LoRa | La radio non ha risposto all'avvio: controlla l'antenna e i collegamenti. Il palmare resta comunque spegnibile tenendo premuto 5 secondi, e continua a riprovare da solo.

### Ripristino radio col magnete

Se un collare resta su parametri radio diversi dal palmare, non lo senti più e non puoi correggerlo da remoto. C'è una via d'uscita che non richiede di aprire il case:

1. Appoggia il magnete sul punto segnato e tienilo per 10 secondi
2. Il collare emette 5 beep rapidi: i parametri radio sono tornati a quelli di fabbrica
3. Riporta anche il palmare allo stesso valore standard (Menu → Avanzate → SF), e torneranno a

Il ripristino tocca solo i parametri radio: l'associazione col palmare, il nome del cane e le altre

Se un apparato resta bloccato su una schermata e non risponde a nulla, l'unico rimedio è scollegare e ricollegare la batteria. Sul collare sigillato questo significa aprire il case.

# 14. Dati tecnici

Voce | Valore
Frequenza radio | 869.525 MHz (banda ISM europea 868)
Tipo di collegamento | LoRa punto-punto diretto, nessuna rete o gateway
Modalità radio | SF regolabile 7–12 (predefinito 8), banda 125 kHz, correzione 4/5
Potenza | Regolabile fino a 22 dBm dal chip, per apparato (vedi capitolo 15)
Aggiornamento posizione | 2.5 s in movimento · 30 s da fermo
Precisione GPS | 2–3 m in campo aperto; 5–10 m sotto vegetazione fitta
Collari associabili | 6
Lunghezza nome | 9 caratteri (6 visibili nella schermata principale)
Memoria tracce | Circolare: la sessione più vecchia lascia posto alla nuova
Esportazione | GPX standard, una traccia per cane
Rete WiFi del palmare | Pi_zaff_sys_DogTrack · password pizaff123 · 192.168.4.1
Watchdog | Attivo: riavvia da solo in caso di blocco del programma
Ricarica | USB-C su entrambi gli apparati

### Cosa significano i numeri del segnale

RSSI | Barrette | Qualità
oltre −95 dBm | 4 | Ottima
−95 / −105 | 3 | Buona
−105 / −113 | 2 | Sufficiente
−113 / −120 | 1 | Al limite
sotto −120 dBm | 0 | Collegamento perso

### HDOP: quanto fidarsi della posizione

Valore | Significato
sotto 2 | Ottimo: satelliti ben distribuiti

2 – 5 | Buono, adatto all'uso normale
5 – 10 | Discreto: posizione un po' incerta
oltre 10 | Scarso: da non prendere alla lettera

L'HDOP misura come sono disposti i satelliti in cielo, non quanti sono: pochi satelliti ben distribuiti danno una posizione migliore di tanti satelliti ammassati nella stessa zona.

# 15. Note su potenza e normativa

Leggi questo capitolo prima del primo uso in esterna. Riguarda un aspetto legale, non solo

### Com'è configurato il sistema

Il firmware è impostato al massimo che l'hardware può erogare: 22 dBm dal chip radio, che sulle schede V4 diventano circa 28 dBm in uscita grazie all'amplificatore integrato.

### Il limite europeo

In Europa, sulla banda usata da questo sistema, il limite di potenza irradiata (ERP) è di 27 dBm. La potenza irradiata non dipende solo dalla radio, ma anche dall'antenna:

ERP = potenza in uscita + guadagno antenna − 2.15

Configurazione | ERP risultante | Rispetto al limite
Scheda V4 + antenna 10 dBi | circa 35.9 dBm | ampiamente sopra
Scheda V4 + antenna 2.5 dBi | circa 28.4 dBm | sopra
Scheda V3 + antenna 10 dBi | circa 29.9 dBm | sopra

### Come rientrare nei limiti

Si abbassa un solo valore nel firmware ( LORA_PWR_DBM ) e si ricompila:

Configurazione | Valore da impostare
Scheda V4 con antenna 10 dBi | 12 – 13
Scheda V4 con antenna 2.5 dBi | 19 – 20
Scheda V3 con antenna 10 dBi | 19

Quanto si perde davvero? Meno di quanto sembri. La portata cresce molto lentamente con la potenza: in bosco, dove l'ambiente assorbe gran parte del segnale, la differenza tra il massimo e il valore a norma è dell'ordine del 20–30% di distanza, non del doppio. Per guadagnare portata reale conviene agire sulla modalità radio e sul posizionamento dell'antenna, che rendono di più.

### Perché esistono questi limiti

La banda 868 MHz è condivisa con altri sistemi, alcuni dei quali importanti: antifurti, apparecchiature mediche, sensori industriali. I limiti servono a far convivere tutti. In Italia il superamento dei limiti di emissione è sanzionato dal Codice delle comunicazioni elettroniche.

La responsabilità dell'uso è di chi lo mette in funzione. Questo è un apparato autocostruito, privo di certificazione: sta a te configurarlo in modo conforme alle norme del posto in cui lo usi.

# 16. Pinout della scheda V4

Riferimento completo dei connettori della scheda Heltec WiFi LoRa 32 V4, con indicazione di cosa è usato dal progetto e cosa non va toccato. Serve se devi rifare un collegamento o aggiungere qualcosa.

USATO usato dal progetto | RISERV. riservato dalla scheda | STRAP. strapping | libero libero

Pin con funzione dedicata sulla V4. Secondo il pin layout ufficiale questi pin sono già impegnati sulla scheda: GPIO 7 e GPIO 2 controllano l'amplificatore radio, GPIO 34 alimenta il connettore GNSS, GPIO 21 resetta il display integrato.

Due eccezioni nel montaggio attuale. Su questo esemplare il GPIO 5 non ha mai risposto (verificato scambiando i fili), quindi la manopola è stata spostata sul GPIO 2; il cicalino è sul GPIO 21 perché i pin provati prima non erano raggiungibili sulla scheda. Entrambi funzionano, ma sono pin che il layout indica come occupati.

Verifica consigliata: con i due apparati distanti qualche decina di metri, guarda l'RSSI in Menu → Info mentre giri la manopola avanti e indietro. Se il valore oscilla o crolla, il GPIO 2 è davvero collegato all'amplificatore e conviene spostare la manopola.

### Connettore J3 (lato sinistro)

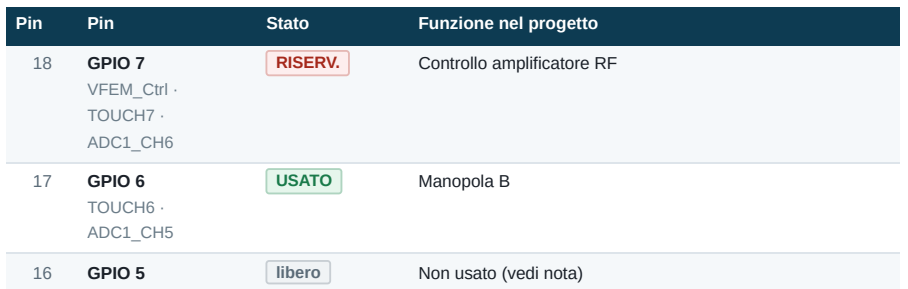
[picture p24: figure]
Pin; Stato; Funzione nel progetto; GPIO 6; TOUCH6 · ADC1_CH5; USATO; Manopola B; GPIO 5; libero; Non usato (vedi nota)

18 | GPIO 7 VFEM_Ctrl · TOUCH7 · ADC1_CH6 | RISERV. | Controllo amplificatore RF

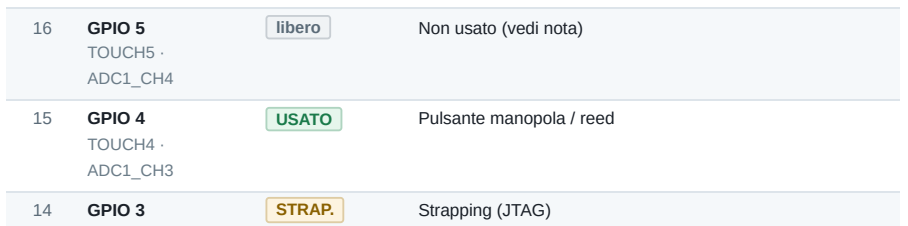
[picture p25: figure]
TOUCH5 · ADC1_CH4; GPIO 4; TOUCH4 · ADC1_CH3; USATO; Pulsante manopola / reed; GPIO 3; STRAP.; Strapping (JTAG)
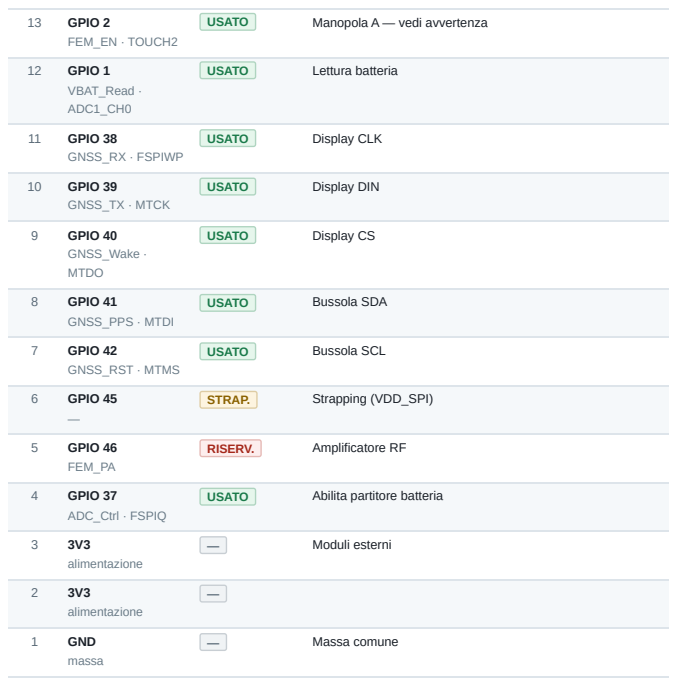
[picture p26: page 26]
GPIO 2; FEM_EN · TOUCH2; USATO; Manopola A — vedi avvertenza; GPIO 1; VBAT_Read · ADC1_CH0; Lettura batteria; GPIO 38; GNSS_RX · FSPIWP; Display CLK; GPIO 39; GNSS_TX · MTCK; Display DIN; GPIO 40; GNSS_Wake · MTDO; Display CS; GPIO 41; GNSS_PPS · MTDI; Bussola SDA; GPIO 42; GNSS_RST · MTMS; Bussola SCL; GPIO 45; STRAP.; Strapping (VDD_SPI); GPIO 46; FEM_PA; RISERV.; Amplificatore RF; GPIO 37; ADC_Ctrl · FSPIQ; Abilita partitore batteria; alimentazione; Moduli esterni; GND; massa; Massa comune

## 16. Pinout V4 (continua)

### Connettore J2 (lato destro)

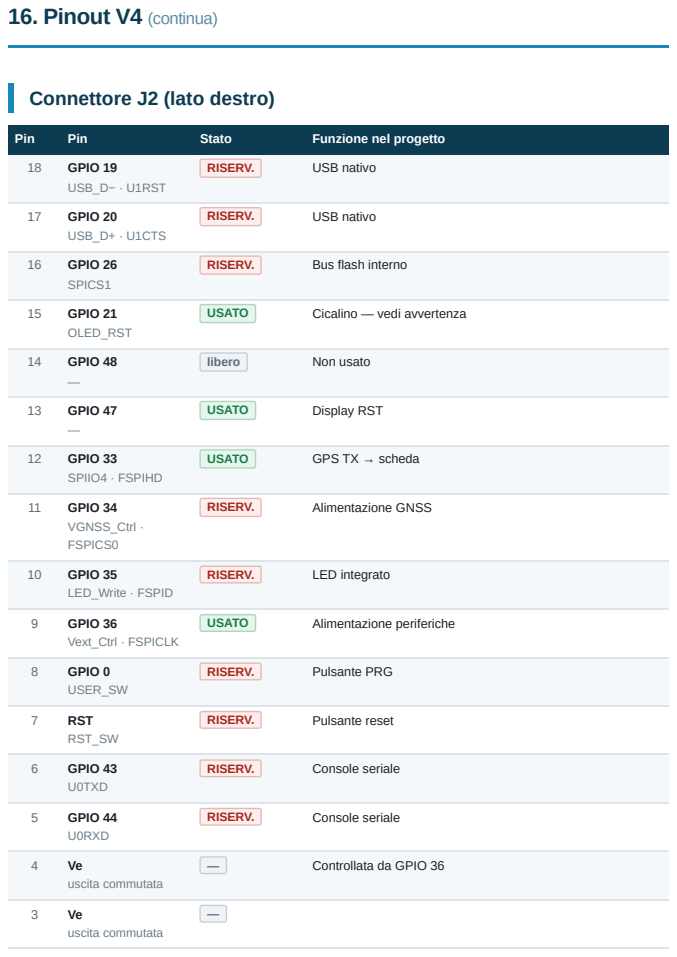
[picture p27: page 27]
GPIO 20; USB_D+ · U1CTS; RISERV.; USB nativo; GPIO 26; SPICS1; Bus flash interno; GPIO 21; OLED_RST; USATO; Cicalino — vedi avvertenza; GPIO 48; libero; Non usato; GPIO 47; Display RST; GPIO 33; SPIIO4 · FSPIHD; GPS TX → scheda; GPIO 34; VGNSS_Ctrl · FSPICS0; Alimentazione GNSS; GPIO 35; LED_Write · FSPID; LED integrato; GPIO 36; Vext_Ctrl · FSPICLK; Alimentazione periferiche; GPIO 0; USER_SW; Pulsante PRG; RST; RST_SW; Pulsante reset; GPIO 43; U0TXD; Console seriale; GPIO 44; U0RXD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

Pin | Pin | Stato | Funzione nel progetto

18 | GPIO 19 USB_D− · U1RST | RISERV. | USB nativo

### Radio, display integrato e altri

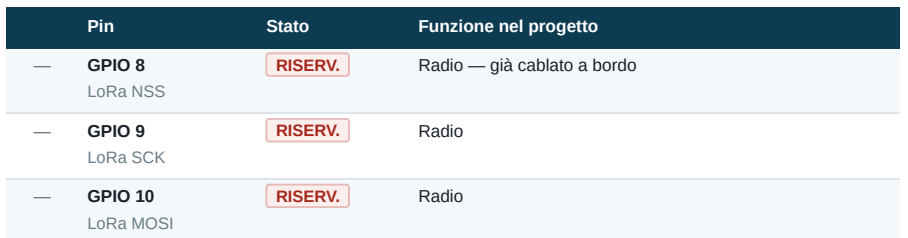
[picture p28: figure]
Pin; Stato; Funzione nel progetto; GPIO 9; LoRa SCK; RISERV.; Radio; GPIO 10; LoRa MOSI

— | GPIO 8 LoRa NSS | RISERV. | Radio — già cablato a bordo

I pin 38–42 sulla V4 sono collegati anche al connettore GNSS dedicato. Restano utilizzabili come pin normali finché quel connettore non viene usato: nel nostro montaggio il GPS è collegato a filo, quindi

Strapping pin. GPIO 3 e 45 vengono letti dal chip all'accensione per decidere come avviarsi. Se un modulo esterno li tiene a livello alto o basso, la scheda può non partire. Vanno lasciati liberi.

# 17. Schema del collare

Tutti i collegamenti da fare. Radio, gestione batteria e presa USB sono già cablati sulla scheda: si collegano solo i moduli esterni.

Modulo | Suo pin | Pin scheda | Note
GPS | TX | GPIO 33 | Incrociato: TX del GPS sull'RX della scheda
| RX | GPIO 16 | Su V3: GPIO 34
| VCC | 3V3 | Mai a 5V
| GND | GND
Accelerometro | SDA | GPIO 41
| SCL | GPIO 42
| VCC | 3V3
| GND | GND
Reed switch | capo 1 | GPIO 4 | Su V3: GPIO 7
| capo 2 | GND | Non ha polarità
Cicalino | + | GPIO 21 | Tipo passivo. Vedi avvertenza
| − | GND
Batteria | JST | connettore scheda | Verificare la polarità
Antenna | u.FL | connettore scheda | Collegare prima di alimentare

### Posizionamento nel case

Antenna GPS rivolta verso l'alto: è la faccia che deve vedere il cielo

Antenna GPS lontana dalla batteria: il pacco può schermare il segnale
Reed switch piatto contro la parete, con la parete assottigliata in quel punto e un segno inciso all'esterno per ritrovarlo
Fili corti e fissati: il collare prende urti e vibrazioni continue
Batteria su biadesivo, mai incollata direttamente

Massa comune. Tutti i GND dei moduli devono arrivare al GND della scheda. Senza massa condivisa i segnali non funzionano o danno letture instabili.

# 18. Schema del palmare

Modulo | Suo pin | Pin scheda | Note
GPS + bussola | TX | GPIO 33 | Incrociato
| RX | GPIO 16 | Su V3: GPIO 34
| SDA | GPIO 41 | Bussola
| SCL | GPIO 42 | Bussola
| VCC | 3V3
| GND | GND
Display | CLK | GPIO 38
| DIN | GPIO 39
| CS | GPIO 40
| DC | GPIO 15 | Su V3: GPIO 21
| RST | GPIO 47
| VCC | 3V3
| GND | GND
Manopola | CLK (A) | GPIO 2 | Vedi avvertenza sotto
| DT (B) | GPIO 6
| SW | GPIO 4 | Su V3: GPIO 7
| + | 3V3
| GND | GND
Cicalino | + | GPIO 21 | Vedi avvertenza
| − | GND
Batteria | JST | connettore scheda
Antenna | u.FL | connettore scheda

### Posizionamento nel case

Display in verticale, con il connettore verso il basso

Bussola lontana dal magnete: almeno 6–7 cm, angolo opposto del case Bussola lontana dalla batteria e da parti metalliche
Manopola raggiungibile con una mano sola: la userai con i guanti

Il magnete e la bussola. Se tieni il magnete del collare nello stesso case del palmare, calibra la bussola con il magnete già al suo posto: il campo fisso viene compensato. Spostandolo dopo, la freccia sbaglia finché non lo rimetti dov'era.

Pi_Zaff System · DogTrack · manuale d'uso firmware v2.14
Sistema autocostruito — nessuna garanzia implicita di funzionamento o conformità

# Riepilogo comandi

Pagina da consultare al volo, senza cercare nel manuale.

### Palmare

Gesto | Effetto
Tieni premuto 2 s | Accende
Tieni premuto 5 s | Spegne (con barra di conferma)
Ruota in schermata principale | Cambia cane
Click in schermata principale | Apre il menu
Ruota nelle liste | Scorre le voci
Ruota nelle schermate informative | Esce
Click dove c'è un'azione extra | Esegue l'azione (spegni WiFi, cancella tracce)

### Collare (magnete)

Durata | Effetto
2 secondi (da spento) | Accende — 1 beep
3 secondi (da acceso o in standby) | Spegne — 3 beep
10 secondi | Ripristino radio — 5 beep rapidi

### Suoni

Suono | Significato
Palmare: 3 toni in discesa | Segnale perso
Palmare: 2 toni in salita | Segnale ritrovato
Palmare: 2 toni lunghi | Cane in ferma
Palmare: 3 beep uguali | Batteria collare quasi scarica
Collare: 3 toni in discesa | Messo in standby dal palmare
Collare: 2 toni in salita | Svegliato dal palmare

Collare: 2 beep ogni 30 s | Non sente più il palmare

### Rete WiFi

Nome rete | Pi_zaff_sys_DogTrack
Password | pizaff123
Indirizzo | 192.168.4.1

# Note — prove di portata

Distanze raggiunte, zone difficili, valori di SF provati.

# Note — tarature

Valori modificati e perche': potenza, SF, soglie.

# Note — manutenzione

Interventi fatti, parti sostituite, date di ricarica.

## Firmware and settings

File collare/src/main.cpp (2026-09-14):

// ============================================================
//  PiZaff DogTrack - Collare GPS-LoRa
//  Copyright (C) 2026 Pietro Zaffarano
//
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
// ============================================================
//  COLLARE GPS-LoRa  v1.5
//  ESP32-S3 + SX1262 (Heltec V3 pinout) + NEO-M8N + MPU6050
//
//  Funzioni:
//   - Fix GPS continuo (UART1)
//   - TX LoRa adattivo: cane in movimento = invio rapido,
//     cane fermo = invio lento (risparmio batteria)
//   - Lettura tensione batteria (partitore on-board Heltec V3)
//   - Pacchetto binario compatto con CRC gestito da RadioLib
// ============================================================

#include <Arduino.h>
#include <RadioLib.h>
#include <TinyGPSPlus.h>
#include <Wire.h>
#include <MPU6050.h>
#include <Preferences.h>
#include "esp_sleep.h"
#include "driver/gpio.h"
#include "driver/rtc_io.h"

// Modalita' di sleep memorizzata in RTC (sopravvive al deep sleep).
// DEVE stare qui, PRIMA di goToSleep()/confirmPowerOnCollare() che la
// usano piu' sotto - una variabile globale va dichiarata prima del
// primo punto in cui viene referenziata nel file, altrimenti il
// compilatore da' errore "was not declared in this scope".
RTC_DATA_ATTR static uint8_t rtcSleepMode = 0;   // 0=spento tot., 1=standby radio
// Vero se confirmPowerOnCollare() ha rilevato il gesto di reset di
// fabbrica (magnete tenuto 10s all'accensione): il reset vero e proprio
// (currentSF/currentPwr, che dipendono da costanti dichiarate piu' sotto
// nel file) viene applicato in setup() appena sono disponibili.
static bool factoryResetPending = false;

// Reed switch: dichiarato QUI perche' goToSleep()/confirmPowerOnCollare()
// piu' sotto lo usano. Prima il numero di pin era scritto a mano in 5
// punti: spostando il pin sulla V4 quei punti sarebbero rimasti al 7
// (VFEM_Ctrl) e lo spegnimento avrebbe smesso di funzionare.
#ifdef BOARD_V4
static const int8_t PIN_REED = 4;      // V4: GPIO 7 e' VFEM_Ctrl (ampli RF!)
#else
static const int8_t PIN_REED = 7;
#endif

// Amplificatore RF esterno (solo V4): a differenza della V3, va acceso
// esplicitamente via software - senza questi pin resta in modalita' ridotta.
// Scritta sulla scheda: "V4.3" -> front-end KCT8103L (non GC1109/V4.2, che
// useremmo se leggesse V4.2 - i due chip hanno una mappatura pin diversa,
// vedi note di Meshtastic per heltec_v4). Confermato anche a posteriori:
// GPIO5 "difettoso" trovato mesi fa testando l'encoder non era un pin
// guasto, era gia' collegato al CTX di questo front-end.
//   GPIO7 = VFEM (alimentazione front-end, sempre HIGH)
//   GPIO2 = CSD  (chip enable, sempre HIGH)
//   GPIO5 = CTX  (seleziona LNA in ricezione / PA in trasmissione - va
//                 gestito da RadioLib con setRfSwitchPins(), vedi
//                 applyFemFixV4(): HIGH solo durante il burst di TX,
//                 LOW il resto del tempo per avere il guadagno LNA in RX)
// Nessun conflitto con altri pin usati su questa scheda (verificato sopra).
#ifdef BOARD_V4
static const int8_t PIN_PA_VFEM = 7;
static const int8_t PIN_PA_CSD  = 2;
static const int8_t PIN_PA_CTX  = 5;
#endif
// Buzzer: dichiarato QUI (invece che piu' sotto con gli altri pin) per lo
// stesso motivo del reed - confirmPowerOnCollare() ora lo usa per i 5 beep
// di conferma del reset di fabbrica.
// GPIO48 non e' esposto sugli header di questa scheda (assente dallo schema
// pinout) - quasi certamente riservato al LED RGB integrato sui moduli
// ESP32-S3, non un pin generico per periferiche esterne. Spostato su
// GPIO21 (confermato raggiungibile sulla scheda fisica): nessun altro uso
// su questa scheda (il collare non ha display).
static const int8_t PIN_BUZZER = 21;
static void beepN(int n, int freq = 2000, int durMs = 120, int gapMs = 130);  // prototipo

// Vext (alimentazione GPS/MPU6050, LOW = ON): dichiarato QUI (invece che
// piu' sotto con ADC_CTRL) per lo stesso motivo del reed - serve dentro
// powerDownPeripherals()/goToSleep() piu' in basso.
static const int8_t PIN_VEXT = 36;
// ADC_CTRL (partitore batteria, HIGH = scollegato) e LORA_RST (reset del
// chip radio): dichiarati QUI per lo stesso motivo, servono a
// powerDownPeripherals() piu' sotto - i loro "gemelli" (VBAT_ADC, e gli
// altri pin SPI della radio) restano dichiarati piu' in basso.
static const int8_t PIN_ADC_CTRL = 37;
static const int8_t PIN_LORA_RST = 12;

// ---------------- ACCENSIONE / SPEGNIMENTO (reed) ------------
// Spegne (e TIENE spento durante il deep sleep vero) tutto cio' che puo'
// restare ad assorbire corrente. Va chiamata da OGNI punto che sta per
// entrare in deep sleep. Scrivere LOW un istante prima di
// esp_deep_sleep_start() SENZA gpio_hold_en() non basta: un pin non tenuto
// torna floating (non "diventa LOW"), e se il chip dall'altra parte ha un
// pull-up interno sul suo ingresso di enable (comune sui front-end RF),
// floating puo' essere letto come ancora HIGH. gpio_hold_en() richiede solo
// un GPIO "output-capable" (verificato nell'header driver/gpio.h di
// ESP-IDF) - non e' ristretto ai soli pin RTC 0-21, funziona anche su
// GPIO36/37 (Vext/ADC_CTRL).
//
// Il reset della radio (RST tenuto LOW) sostituisce l'affidarsi a
// radio.sleep() chiamato caso per caso - due punti del codice arrivano al
// deep sleep senza mai aver chiamato radio.sleep() (magnete tolto durante
// il reset di fabbrica, e il retry-loop se la radio non si inizializza):
// in quei casi l'SX1262 resterebbe in STDBY_RC post-POR (~1.5mA) per
// tutto il sonno. Tenerlo in reset hardware funziona sempre, a prescindere
// da che comandi SPI siano gia' stati mandati.
// resetRadio=true SOLO per lo spegnimento vero (goToSleep()): tiene
// l'SX1262 in reset hardware perche' li' non deve rispondere piu' a
// nessuno. false per lo standby (enterStandby()/resumeStandbySleep()): la
// radio li' deve restare accesa e in ascolto (startReceiveDutyCycleAuto())
// per il risveglio via burst del palmare - resettarla in quel momento
// (bug reale trovato in revisione: prima veniva resettata SEMPRE, anche
// qui, subito prima o dopo aver ordinato l'ascolto autonomo, mandando quel
// comando SPI a un chip in reset) rompeva silenziosamente lo standby: il
// collare restava risvegliabile solo col magnete finche' non si staccava
// e riattaccava la batteria.
static void powerDownPeripherals(bool resetRadio) {
  digitalWrite(PIN_VEXT, HIGH);              // GPS/MPU6050 off
  gpio_hold_en((gpio_num_t)PIN_VEXT);
  digitalWrite(PIN_ADC_CTRL, HIGH);          // partitore batteria scollegato
  gpio_hold_en((gpio_num_t)PIN_ADC_CTRL);
  if (resetRadio) {
    pinMode(PIN_LORA_RST, OUTPUT);
    digitalWrite(PIN_LORA_RST, LOW);         // radio in reset hardware
    gpio_hold_en((gpio_num_t)PIN_LORA_RST);
  }
  // Pull-up RTC esplicito sul reed: necessario per l'EXT1 usato dallo
  // standby (documentato: i pull-up normali non sopravvivono se le
  // periferiche RTC sono spente), probabilmente ridondante per l'EXT0 del
  // vero spegnimento (che invece tiene le periferiche RTC accese da solo) -
  // ma costa zero metterlo comunque su entrambi i casi.
  rtc_gpio_pullup_en((gpio_num_t)PIN_REED);
  rtc_gpio_pulldown_dis((gpio_num_t)PIN_REED);
#ifdef BOARD_V4
  digitalWrite(PIN_PA_CSD,  LOW);
  digitalWrite(PIN_PA_VFEM, LOW);
  gpio_hold_en((gpio_num_t)PIN_PA_CSD);
  gpio_hold_en((gpio_num_t)PIN_PA_VFEM);
#endif
  gpio_deep_sleep_hold_en();
}

// Da spento: magnete tenuto 2s sul case = accensione.
// Da acceso: magnete tenuto 3s = spegnimento (deep sleep).
// Il tempo minimo evita toggle accidentali (es. collare vicino a metallo).
static void goToSleep() {
  powerDownPeripherals(true);
  rtcSleepMode = 0;                          // spento totale: sveglia SOLO a magnete
  esp_sleep_enable_ext0_wakeup((gpio_num_t)PIN_REED, 0);
  esp_deep_sleep_start();
}

static void confirmPowerOnCollare() {
  esp_sleep_wakeup_cause_t wc = esp_sleep_get_wakeup_cause();
  if (wc != ESP_SLEEP_WAKEUP_EXT0 && wc != ESP_SLEEP_WAKEUP_EXT1) return; // primo avvio
  uint32_t t0 = millis();
  while (digitalRead(PIN_REED) == LOW) {
    if (millis() - t0 >= 2000) {
      // Acceso. Se il magnete resta appoggiato altri 8s (10s totali dalla
      // pressione), e' il gesto di reset di fabbrica dei parametri radio
      // (SF/potenza) - l'unica via di recupero fisica su un dispositivo
      // senza schermo, per il caso limite in cui il ciclo SF automatico
      // da solo non basti. Il reset vero (currentSF/saveSF, dichiarati
      // piu' sotto) viene applicato in setup(); qui segnalo solo che va
      // fatto, e do il feedback sonoro subito mentre il magnete e' ancora
      // li' cosi' l'utente sa che e' scattato.
      pinMode(PIN_BUZZER, OUTPUT);
      bool didReset = false;
      while (digitalRead(PIN_REED) == LOW) {
        if (!didReset && millis() - t0 >= 10000) {
          didReset = true;
          factoryResetPending = true;
          beepN(5, 2000, 100, 100);
        }
        delay(50);
      }
      return;
    }
    delay(20);
  }
  goToSleep();   // magnete tolto troppo presto: rispegni
}

// ---------------- PIN (Heltec WiFi LoRa 32 V3 / cloni) -------
// LoRa SX1262 (PIN_LORA_RST dichiarato piu' in alto, vedi commento li' -
// serve a powerDownPeripherals())
static const int8_t PIN_LORA_NSS  = 8;
static const int8_t PIN_LORA_SCK  = 9;
static const int8_t PIN_LORA_MOSI = 10;
static const int8_t PIN_LORA_MISO = 11;
static const int8_t PIN_LORA_BUSY = 13;
static const int8_t PIN_LORA_DIO1 = 14;

// GPS NEO-M8N su UART1 (pin liberi sull'header V3)
// Su V4 il GPIO 34 e' VGNSS_Ctrl (funzione dedicata a bordo): il TX
// del GPS viene spostato su GPIO 16, libero. Vedi platformio.ini.
static const int8_t PIN_GPS_RX = 33;   // ESP32 RX  <- GPS TX
#ifdef BOARD_V4
static const int8_t PIN_GPS_TX = 16;   // V4: 34 e' VGNSS_Ctrl
#else
static const int8_t PIN_GPS_TX = 34;   // ESP32 TX  -> GPS RX
#endif

// MPU6050 su I2C secondario (l'I2C 17/18 e' occupato dall'OLED)
static const int8_t PIN_SDA = 41;
static const int8_t PIN_SCL = 42;

// Buzzer passivo (feedback acustico accensione/spegnimento):
// + su GPIO48, - su GND (PIN_BUZZER dichiarato piu' in alto, vedi commento
// li'). Sostituisce il LED di stato: col collare dentro il case sigillato
// e coperto dal pelo, un beep si sente, un LED non si vede.

// Reed switch magnetico (accensione/spegnimento senza fori nel case):
// un capo a GPIO7, l'altro a GND. Magnete avvicinato = contatto chiuso.
// Batteria (Heltec V3: ADC su GPIO1, abilitazione partitore su GPIO37)
static const int8_t PIN_VBAT_ADC  = 1;
// PIN_ADC_CTRL e PIN_VEXT (alimentazione periferiche esterne, LOW = ON su
// V3) sono dichiarati piu' in alto, vedi commento li'.

// ---------------- PARAMETRI RADIO ----------------------------
static const float    LORA_FREQ    = 869.525f;  // MHz, banda EU 10% duty
static const float    LORA_BW      = 125.0f;    // kHz
static const uint8_t  LORA_SF      = 8;         // compromesso portata/refresh
static const uint8_t  LORA_CR      = 5;         // 4/5
static const uint8_t  LORA_SYNC    = 0xA7;      // rete privata
// Tensione TCXO passata a radio.begin(): su V4 1.8V e' il valore indicato
// dal file di configurazione Meshtastic per heltec_v4 per il suo TCXO. Sulla
// V3 NON abbiamo questa conferma - resta al default RadioLib (1.6V, quello
// gia' usato finora, quindi zero rischio di regressione li'). Un TCXO
// alimentato alla tensione sbagliata puo' non stabilizzarsi bene, con
// perdita di precisione in frequenza.
#ifdef BOARD_V4
static const float LORA_TCXO_V = 1.8f;
#else
static const float LORA_TCXO_V = 1.6f;
#endif
// POTENZA TX — impostata al MASSIMO erogabile dalla scheda.
//
// 22 = limite tecnico del chip SX1262 (RadioLib rifiuta valori superiori
// e radio.begin() fallisce). Sulla Heltec V4 l'amplificatore esterno
// porta l'uscita della scheda a ~28 dBm, il suo massimo dichiarato.
//
// COSA COMPORTA (ERP = uscita_scheda + guadagno_antenna - 2.15):
//   V4 + antenna 10 dBi  -> ~35.9 dBm ERP   (limite EU 27)
//   V4 + antenna FPC 2.5 -> ~28.4 dBm ERP   (limite EU 27)
// Per restare nei limiti EU: 12-13 con la 10 dBi, 19-20 con la FPC.
//
// ASSORBIMENTO: a piena potenza il PA della V4 tira parecchia corrente
// durante l'impulso TX. Se in trasmissione vedi riavvii casuali, e' un
// calo di tensione (batteria scarica, connettore/cavi sottili): scendi
// di qualche dBm o controlla l'alimentazione.
static const int8_t   LORA_PWR_DBM = 22;
static const uint16_t LORA_PREAMB  = 12;

// ID rete: il palmare scarta pacchetti con magic diverso
static const uint16_t PKT_MAGIC = 0xCA9E;

// ---------------- INTERVALLI TX ------------------------------
static const uint32_t TX_FAST_MS = 2500;    // cane in movimento
static const uint32_t TX_SLOW_MS = 30000;   // cane fermo
static const uint32_t MOTION_HOLD_MS = 15000; // resta "fast" per 15s dall'ultimo movimento
static const float    MOTION_G_THRESH = 0.25f; // delta-g per trigger movimento
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
void loop() {
  // ---- SPEGNIMENTO: magnete tenuto sul case per 3 secondi -----
  static uint32_t reedStart = 0;
  if (digitalRead(PIN_REED) == LOW) {
    if (reedStart == 0) reedStart = millis();
    if (millis() - reedStart >= 3000) {
      Serial.println(F("[COLLARE] spegnimento (magnete)"));
      beepN(3);                                // 3 beep: mi sto spegnendo
      radio.sleep();
      digitalWrite(PIN_VEXT, HIGH);            // spegni GPS
      while (digitalRead(PIN_REED) == LOW) delay(50);  // attendi rimozione magnete
      delay(100);
      goToSleep();
    }
  } else {
    reedStart = 0;
  }

  while (gpsSerial.available()) gps.encode(gpsSerial.read());

  bool moving = isMoving();
  bool fixNow = gps.location.isValid() && gps.location.age() < 5000;

  // ---- Rilevamento FERMA: era in azione, ora immobile -----------
  bool txNow = false;
  float spd = (fixNow && gps.speed.isValid()) ? gps.speed.kmph() : 0;
  if (moving) {
    wasActive = true;
    stillSinceMs = 0;
    if (inFerma) { inFerma = false; txNow = true; }   // ferma finita: avvisa subito
  } else {
    if (stillSinceMs == 0) stillSinceMs = millis();
    if (wasActive && !inFerma &&
        millis() - stillSinceMs >= FERMA_STILL_MS && spd < 1.0f) {
      inFerma = true; txNow = true;                    // FERMA! avvisa subito
    }
    if (inFerma && millis() - stillSinceMs >= FERMA_MAX_MS) {
      inFerma = false; wasActive = false; txNow = true; // 3+ min = riposo
    }
  }

  // ---- Beep link perso col palmare (2 beep ogni 120s) ------------
  if (everAcked && millis() - lastAckMs > 60000 &&
      millis() - lastLinkBeepMs > 120000) {
    lastLinkBeepMs = millis();
    beepN(2, 1600, 150, 180);
  }

  // Batteria: controlla ogni 60s (evita letture ADC continue)
  static uint32_t lastBattMs = 0;
  static uint16_t battMv = 3900;
  // Rilevamento carica: nessun pin STAT/CHG dedicato. Una soglia fissa NON
  // funziona - una batteria quasi piena e SCOLLEGATA riposa gia' sopra 4V, e
  // subito dopo lo stacco ci resta ancora un po' (effetto "surface charge"
  // della cella al litio) prima di scendere: qualunque soglia fissa prima o
  // poi la becca come falsa carica. L'unico segnale affidabile e' la
  // TENDENZA: in carica la tensione sale in modo continuo nei minuti; da
  // scollegata, sotto il carico normale della scheda (radio/GPS/display),
  // crolla subito di decine di mV perche' non c'e' piu' corrente del
  // caricatore a compensare l'assorbimento. Quindi: ACCENDI se sale in modo
  // sostenuto su una finestra di qualche minuto, SPEGNI appena scende
  // chiaramente dal massimo visto (niente bisogno di aspettare una discesa
  // "lenta": lo stacco e' un evento netto, non graduale).
  static uint16_t battPeakMv = 0;
  static uint16_t battRefMv = 0;
  static uint32_t battRefMs = 0;
  static bool charging = false;
  const uint32_t BATT_TREND_WINDOW_MS = 180000;  // 3 minuti
  if (millis() - lastBattMs >= 60000 || lastBattMs == 0) {
    lastBattMs = millis();
    battMv = readBatteryMv();
    if (battMv > battPeakMv) battPeakMv = battMv;
    if (battRefMs == 0) { battRefMv = battMv; battRefMs = millis(); }
    if (millis() - battRefMs >= BATT_TREND_WINDOW_MS) {
      if (!charging && (int32_t)battMv - (int32_t)battRefMv >= 12) charging = true;
      battRefMv = battMv;
      battRefMs = millis();
    }
    if (charging && (int32_t)battPeakMv - (int32_t)battMv >= 30) {
      charging = false;
      battPeakMv = battMv;
      battRefMv = battMv;
      battRefMs = millis();
    }
  }
  bool lowBatt = battPercent(battMv) < 15;

  // Link perso (stessa soglia dei 60s usata sopra per il beep): anche da
  // fermo passa all'intervallo veloce, per ritrovare il link prima invece
  // di aspettare fino a 30s tra un tentativo e l'altro. Solo per 15 minuti
  // pero': se il link resta perso piu' a lungo (fuori portata per un bel
  // po', non un buco momentaneo) si torna al ritmo lento normale, per non
  // consumare la batteria trasmettendo veloce a vuoto per ore.
  const uint32_t LINK_LOST_FAST_WINDOW_MS = 15UL * 60000UL;
  uint32_t sinceAckMs = millis() - lastAckMs;
  bool linkLost = everAcked && sinceAckMs > 60000 &&
                  sinceAckMs <= 60000 + LINK_LOST_FAST_WINDOW_MS;
  // Con batteria scarica raddoppia gli intervalli: meglio un refresh
  // piu' lento che un collare morto a meta' battuta.
  uint32_t interval = (moving || linkLost) ? max(TX_FAST_MS, minFastIntervalMs(currentSF)) : TX_SLOW_MS;
  if (lowBatt) interval *= 2;

  if (txNow || millis() - lastTxMs >= interval) {
    lastTxMs = millis();

    CollarPacket pkt = {};
    pkt.magic     = PKT_MAGIC;
    pkt.version   = 4;
    pkt.collar_id = collarId;
    pkt.seq       = txSeq++;

    if (fixNow)  pkt.flags |= 0x01;
    if (moving)  pkt.flags |= 0x02;
    if (lowBatt) pkt.flags |= 0x04;
    if (inFerma) pkt.flags |= 0x08;
    if (charging) pkt.flags |= 0x10;

    // Satelliti "in uso" (campo del GGA): TinyGPSPlus lo aggiorna appena
    // arriva una sentenza valida, indipendentemente dal fix. Lo mandiamo
    // sempre, non solo con fixNow, cosi' sul palmare/web si vede "vedo 3
    // satelliti ma non ancora abbastanza per un fix" invece di un secco 0
    // indistinguibile da "GPS spento/non risponde".
    pkt.sats = (uint8_t)gps.satellites.value();

    if (fixNow) {
      pkt.lat_e7 = (int32_t)(gps.location.lat() * 1e7);
      pkt.lon_e7 = (int32_t)(gps.location.lng() * 1e7);
      pkt.alt_m  = gps.altitude.isValid() ? (uint16_t)constrain(gps.altitude.meters(), 0, 65535) : 0;
      pkt.hdop_x10 = (uint8_t)constrain(gps.hdop.hdop() * 10.0, 0, 255);
      if (gps.speed.isValid())
        pkt.speed_x10 = (uint16_t)constrain(gps.speed.kmph() * 10.0, 0, 65535);
      if (gps.course.isValid())
        pkt.course_deg = (uint16_t)gps.course.deg() % 360;
    }

    pkt.batt_mv  = battMv;
    pkt.batt_pct = battPercent(battMv);

    int st = radio.transmit((uint8_t*)&pkt, sizeof(pkt));
    Serial.printf("[TX] seq=%u fix=%d mov=%d ferma=%d v=%.1f sats=%u batt=%u%% -> %s\n",
                  pkt.seq, fixNow, moving, inFerma, pkt.speed_x10 / 10.0f,
                  pkt.sats, pkt.batt_pct, st == RADIOLIB_ERR_NONE ? "OK" : "ERR");

    // ---- finestra comandi: il palmare risponde con ACK o comando --
    // La finestra scala con SF (vedi ackWindowMs()): a SF alti il pacchetto
    // di risposta del palmare dura di piu', una finestra fissa lo perderebbe.
    CmdPacket cmd;
    if (waitCmd(ackWindowMs(currentSF), cmd)) {
      lastAckMs = millis(); everAcked = true;
      if (sfRecoveryCandidate != 0) {
        // Ero nel ciclo di recupero SF e ho appena ricevuto risposta: questo
        // e' l'SF giusto, lo salvo e smetto di ciclare.
        saveSF(currentSF);
        sfRecoveryCandidate = 0;
      }
      if (cmd.cmd == CMD_STANDBY) {
        enterStandby();   // spento da palmare
      } else if (cmd.cmd == CMD_SET_PWR) {
        // Potenza: indipendente per apparato, nessun rischio di
        // disallineamento - si applica subito, niente prova/rollback.
        currentPwr = (int8_t)cmd.p1;
        radio.setOutputPower(currentPwr);
        savePwr(currentPwr);
      } else if (cmd.cmd == CMD_SET_SF && cmd.p1 >= 7 && cmd.p1 <= 12 &&
                 cmd.p1 != currentSF && sfTrialOld == 0) {
        // SF: deve combaciare sui due apparati o il collegamento si rompe.
        // Confermo SUBITO al vecchio SF (il palmare aspetta questo prima
        // di passare lui stesso al nuovo SF), POI passo al nuovo SF - mai
        // il contrario, altrimenti la conferma non arriverebbe mai.
        CmdPacket ack;
        ack.magic = CMD_MAGIC; ack.version = 2; ack.cmd = CMD_ACK;
        ack.collar_id = collarId; ack.seq = 0; ack.p1 = cmd.p1;
        delay(15);
        radio.transmit((uint8_t*)&ack, sizeof(ack));
        sfTrialOld = currentSF;
        currentSF = cmd.p1;
        radio.setSpreadingFactor(currentSF);
        sfTrialStartMs = millis();
      }
    }

    // Cambio SF in prova: se il palmare torna a farsi sentire (qualsiasi
    // scambio valido) DOPO il passaggio al nuovo SF, e' la conferma che
    // anche lui e' passato al nuovo SF - si salva su NVS e la prova finisce.
    // Se entro SF_TRIAL_MS non arriva nulla, si torna da soli al vecchio SF:
    // nessuno resta orfano per un comando che non e' arrivato a destinazione.
    if (sfTrialOld != 0) {
      if (everAcked && lastAckMs >= sfTrialStartMs) {
        saveSF(currentSF);
        sfTrialOld = 0;
      } else if (millis() - sfTrialStartMs >= SF_TRIAL_MS) {
        currentSF = sfTrialOld;
        radio.setSpreadingFactor(currentSF);
        sfTrialOld = 0;
      }
    }
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

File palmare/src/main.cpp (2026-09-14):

// ============================================================
//  PiZaff DogTrack - Palmare GPS-LoRa
//  Copyright (C) 2026 Pietro Zaffarano
//
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
// ============================================================
//  PALMARE GPS-LoRa  v1.5  (multi-cane, stile Garmin)
//  ESP32-S3 + SX1262 + NEO-M8N + QMC5883L + Sharp Memory 1.3"
// ============================================================

#include <Arduino.h>
#include <RadioLib.h>
#include <TinyGPSPlus.h>
#include <Wire.h>
#include <SPI.h>
#include <Adafruit_GFX.h>
#include <Adafruit_SSD1306.h>
#include <SPI.h>
#include <QMC5883LCompass.h>
#include <Preferences.h>
#define USE_BLE 0
#if USE_BLE
  #include <BLEDevice.h>
  #include <BLEServer.h>
  #include <BLEUtils.h>
  #include <BLE2902.h>
#endif
#include <WiFi.h>
#include <WebServer.h>
#include <LittleFS.h>
#include "esp_sleep.h"
#include "esp_task_wdt.h"
#include "driver/gpio.h"
#include "driver/rtc_io.h"

static const int8_t PIN_LORA_NSS  = 8;
static const int8_t PIN_LORA_SCK  = 9;
static const int8_t PIN_LORA_MOSI = 10;
static const int8_t PIN_LORA_MISO = 11;
static const int8_t PIN_LORA_RST  = 12;
static const int8_t PIN_LORA_BUSY = 13;
static const int8_t PIN_LORA_DIO1 = 14;
// ============================================================
//  PIN — differenze V3 / V4 (BOARD_V4 definito in platformio.ini)
//
//  Sulla V4 tre pin che usavamo hanno una funzione DEDICATA a bordo:
//   GPIO 7  = VFEM_Ctrl   -> controllo dell'amplificatore RF (il PA che
//                            porta l'uscita a 28 dBm). Usarlo come
//                            ingresso pulsante interferirebbe con la
//                            trasmissione ad alta potenza.
//   GPIO 34 = VGNSS_Ctrl  -> alimentazione del connettore GNSS
//   GPIO 21 = OLED_RST    -> reset dell'OLED integrato
//  Su V4 vengono quindi spostati su GPIO liberi (4, 16, 15).
//
//  Corretti e invariati su entrambe: LoRa 8-14, VBAT_Read=1,
//  ADC_Ctrl=37, Vext_Ctrl=36 (verificati sul pin layout ufficiale).
//
//  NOTA: 38/39/40/41/42 sulla V4 sono instradati anche al connettore
//  GNSS (SH1.25-8pin). Restano usabili come GPIO normali finche' quel
//  connettore non viene usato — che e' il nostro caso, il GPS lo
//  colleghiamo a filo.
// ============================================================
static const int8_t PIN_GPS_RX = 33;
#ifdef BOARD_V4
static const int8_t PIN_GPS_TX = 16;   // V4: 34 e' VGNSS_Ctrl
#else
static const int8_t PIN_GPS_TX = 34;
#endif
static const int8_t PIN_SDA = 41;
static const int8_t PIN_SCL = 42;
static const int8_t PIN_LCD_SCK = 38;
static const int8_t PIN_LCD_DI  = 39;
static const int8_t PIN_LCD_CS  = 40;
#ifdef BOARD_V4
static const int8_t PIN_LCD_DC  = 15;  // V4: 21 e' OLED_RST integrato
#else
static const int8_t PIN_LCD_DC  = 21;
#endif
static const int8_t PIN_LCD_RST = 47;
// GPIO5 confermato difettoso su questa scheda (test con ponticello e scambio
// dei fili: il segnale non arriva mai su GPIO5, sempre e solo su GPIO6,
// indipendentemente da quale filo dell'encoder ci sia collegato) - canale A
// spostato su GPIO2, verificato libero/funzionante.
#ifdef BOARD_V4
// V4: GPIO2 serve come CSD per l'amplificatore RF esterno (vedi PIN_PA_*
// sotto) - il canale A dell'encoder si sposta su GPIO18, libero su questa
// scheda. NON ANCORA VERIFICATO fisicamente: stesso test fatto per GPIO5
// (ponticello/scambio fili) va rifatto qui prima di fidarsi al 100%.
static const int8_t PIN_ENC_A  = 18;
#else
static const int8_t PIN_ENC_A  = 2;
#endif
static const int8_t PIN_ENC_B  = 6;
#ifdef BOARD_V4
static const int8_t PIN_ENC_SW = 4;    // V4: 7 e' VFEM_Ctrl (ampli RF!)
#else
static const int8_t PIN_ENC_SW = 7;
#endif
// GPIO 4 e 7 sono entrambi RTC-capable: l'accensione da deep sleep
// funziona su tutte e due le schede.
static const int8_t PIN_VBAT_ADC = 1;
static const int8_t PIN_ADC_CTRL = 37;
static const int8_t PIN_VEXT     = 36;

// Amplificatore RF esterno (solo V4): va acceso esplicitamente via software,
// altrimenti resta in "bypass mode" a potenza ridotta - stesso discorso gia'
// fatto e verificato sul collare. Scritta sulla scheda: "V4.3" -> front-end
// KCT8103L (non GC1109/V4.2). GPIO7=VFEM (alimentazione, sempre HIGH),
// GPIO2=CSD (chip enable, sempre HIGH, richiede lo spostamento di PIN_ENC_A
// sopra), GPIO5=CTX (LNA in RX / PA in TX, gestito da RadioLib con
// setRfSwitchPins - vedi applyFemFixV4()).
// GPIO5 e' lo stesso pin segnato "difettoso" mesi fa testando l'encoder
// (mai spostato oltre GPIO2 prima d'ora): non era guasto, era gia'
// collegato al front-end.
#ifdef BOARD_V4
static const int8_t PIN_PA_VFEM = 7;
static const int8_t PIN_PA_CSD  = 2;
static const int8_t PIN_PA_CTX  = 5;
#endif

static const float    LORA_FREQ    = 869.525f;
static const float    LORA_BW      = 125.0f;
static const uint8_t  LORA_SF      = 8;
static const uint8_t  LORA_CR      = 5;
static const uint8_t  LORA_SYNC    = 0xA7;
// Tensione TCXO passata a radio.begin(): stesso discorso e stessa fonte del
// collare (vedi commento gemello li') - 1.8V su V4, default RadioLib 1.6V
// su V3 (nessuna conferma per la V3, si resta al comportamento di sempre).
#ifdef BOARD_V4
static const float LORA_TCXO_V = 1.8f;
#else
static const float LORA_TCXO_V = 1.6f;
#endif
// POTENZA TX — impostata al MASSIMO erogabile dalla scheda.
//
// 22 = limite tecnico del chip SX1262 (RadioLib rifiuta valori superiori
// e radio.begin() fallisce). Sulla Heltec V4 l'amplificatore esterno
// porta l'uscita della scheda a ~28 dBm, il suo massimo dichiarato.
//
// COSA COMPORTA (ERP = uscita_scheda + guadagno_antenna - 2.15):
//   V4 + antenna 10 dBi  -> ~35.9 dBm ERP   (limite EU 27)
//   V4 + antenna FPC 2.5 -> ~28.4 dBm ERP   (limite EU 27)
// Per restare nei limiti EU: 12-13 con la 10 dBi, 19-20 con la FPC.
//
// ASSORBIMENTO: a piena potenza il PA della V4 tira parecchia corrente
// durante l'impulso TX. Se in trasmissione vedi riavvii casuali, e' un
// calo di tensione (batteria scarica, connettore/cavi sottili): scendi
// di qualche dBm o controlla l'alimentazione.
static const int8_t   LORA_PWR_DBM = 22;
static const uint16_t LORA_PREAMB  = 12;
static const uint16_t PKT_MAGIC    = 0xCA9E;

#pragma pack(push, 1)
struct CollarPacket {
  uint16_t magic;
  uint8_t  version;
  uint8_t  flags;      // bit0 fix, bit1 mov, bit2 batt scarica, bit3 FERMA, bit4 in carica
  uint32_t collar_id;
  int32_t  lat_e7;
  int32_t  lon_e7;
  uint16_t alt_m;
  uint16_t speed_x10;
  uint16_t course_deg;
  uint8_t  sats;
  uint8_t  hdop_x10;
  uint8_t  batt_pct;
  uint16_t batt_mv;
  uint16_t seq;
};
#pragma pack(pop)
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

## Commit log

2026-09-03 Initial commit: firmware collare + palmare (v2.19 V4pins), CAD e documentazione
    [palmare dogtrk.3mf, palmare dogtrk.stl, partitions_pizaff.csv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]
2026-09-14 Corregge anno di copyright (2026)
2026-09-14 Aggiorna README dopo rimozione cartella cad/

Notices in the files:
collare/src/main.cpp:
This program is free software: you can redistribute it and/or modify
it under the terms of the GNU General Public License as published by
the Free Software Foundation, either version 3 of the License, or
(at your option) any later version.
